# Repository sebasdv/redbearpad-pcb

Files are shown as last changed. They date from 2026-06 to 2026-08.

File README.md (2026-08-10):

# RedBearPad v2 — Mando XInput de 12 botones para RedBearLab Blend Micro

PCB de 96 × 64 mm. Mando estilo SNES orientado a juegos de plataforma que se
enumera como **control de Xbox 360 (XInput)** y Steam reconoce de forma nativa.
12 entradas a GND con pull-up interno (activo en bajo): **10 switches Redragon
SMD RGB MX Low Profile** + **2 tact CAX C39832249** (Start/Select). La Blend
Micro V1.0 va enchufada en la cara inferior (headers hembra 2×14, USB hacia el
borde superior). **Sin OLED** (eliminada respecto de la v1).

## Layout (vista desde arriba, grilla de 16 mm)

```
 L  Sel  ·  Sta  R       (fila y=16)   Sel/Sta = tact CAX
 ·  Up   ·   X   Y       (fila y=32)
 Iz Dn  Der  A   B       (fila y=48)   cruceta: Up arriba de Dn; Izq/Der en y=48
```

## Archivos

- `redbearpad.kicad_pro/.kicad_sch/.kicad_pcb` — proyecto KiCad 9 (ruteado, DRC limpio en cobre).
- `firmware/redbearpad_xinput/` — firmware XInput de 12 botones (el de producción).
- `scripts/gen_sch.py`, `scripts/gen_pcb.py` — regeneran esquemático y placement
  (ejecutar con el Python de KiCad: `...\KiCad\9.0\bin\python.exe`).
  ⚠️ Regenerar el PCB **borra el ruteo**; el ruteo actual está en el `.kicad_pcb` versionado.
- `scripts/verify_netlist.py` — valida el netlist contra el contrato de diseño (12 entradas).
- `scripts/attach_3d_models.py` — adjunta modelos 3D a los footprints ya colocados en el
  `.kicad_pcb` **sin regenerar la placa** (a diferencia de `gen_pcb.py`, no toca el ruteo).
  Solo hace falta si se rutea a mano sobre un board viejo sin modelos; una regeneración
  completa con `gen_pcb.py` ya los trae, porque viven en el `.kicad_mod` de la librería.
- `fabrication/gerbers/` — Gerbers + drill (F.Cu, B.Cu, Edge_Cuts, NPTH/PTH) regenerados.
- `docs/superpowers/specs/` — diseño aprobado de la v2.
- `docs/render_top.png`, `docs/render_bottom.png` — vistas previas 3D (`kicad-cli pcb render`).

## Ruteo

11 de las 12 nets ruteadas con **Freerouting** (autorouter, vía DSN/SES); la net
restante (SW7→A0) se ruteó a mano con una vía para cruzar la pared de pistas de
SW6/SW8. **DRC de cobre: 0 sin conectar, 0 cortos, 0 clearance.** Quedan 8 avisos
de serigrafía sobre los pads de los tact (cosméticos: el fabricante recorta la
silk sobre pads automáticamente).

## Pedido en JLCPCB

1. jlcpcb.com → "Order now" → subir un ZIP con el contenido de `fabrication/gerbers/`.
2. Opciones: 2 capas, 1.6 mm, HASL (todo por defecto sirve). Sin ensamblado.

## ⚠️ Antes de pagar

Medir con pie de metro un switch real contra el footprint: poste central Ø4.4 mm
en el centro; pines a (3.8, 3.8) y (0, 6.5) mm del centro, Ø1.2 mm. Si no
coincide, ajustar `libs/redbearpad.pretty/SW_Redragon_LowProfile_PCB_1.00u.kicad_mod`.
Verificar también el tact `SW_Tact_CAX_4.5x4.5` (cuerpo 4.5×4.5 mm, 4 patas).

## Conexiones (firmware XInput)

| Función | Pin Arduino | Botón XInput |
|---|---|---|
| Arriba / Abajo / Izquierda / Derecha | D3 / D1 / D2 / D0 | stick izq. + D-pad |
| X / Y (cara, fila superior) | D11 / D12 | X / Y |
| A / B (cara, fila inferior) | A0 / A1 | A / B |
| L / R | D8 / D9 | LB / RB |
| Select / Start | D5 / D10 | BACK / START |

Todas en `INPUT_PULLUP`, activas en bajo. La cruceta se manda como stick izquierdo
**y** D-pad para máxima compatibilidad.

Los 4 botones de cara forman un cuadrado 2×2, así que se asignan como el diamante
Xbox girado 45°, respetando las cuatro relaciones de la convención (**Y arriba, A
abajo, X izquierda, B derecha**):

```
 X  Y
 A  B
```

## Compilar y flashear (XInput)

- Placa: **"Arduino Micro w/ XInput"** (FQBN `xinput:avr:micro`, 16 MHz) del paquete
  [ArduinoXInput_Boards](https://raw.githubusercontent.com/dmadison/ArduinoXInput_Boards/master/package_dmadison_xinput_index.json)
  + librería **XInput** (David Madison). El variant 16 MHz calza con el cristal de
  la Blend Micro.
- XInput **no es CDC**: no hay Serial Monitor (LED 13 hace heartbeat). Para
  reflashear, hacer **doble-reset manual** para entrar al bootloader.

## Modelos 3D

- **Switches Redragon MX Low Profile** (los 10): modelo real
  (`libs/redbearpad.3dshapes/SW_Redragon_LowProfile_PCB_1.00u.step`), rotado 180°.
- **Blend Micro**: modelo real modelado por el usuario en Fusion 360 — PCB
  roja con los dos headers de 14 pines y un conector micro-USB detallado,
  que asoma por el borde superior de la placa tal como en la física real.
  El footprint usa el `BlendMicro_Module_V1.step` **original**, con
  `rotate (xyz 0 180 0)` en el bloque `(model ...)`: el modulo necesitaba
  dos correcciones (mirror en X para que el header quedara en el lado
  correcto, y flip en Z porque los pines apuntaban hacia afuera en vez de
  hacia J1/J2) y espejar en dos ejes distintos equivale matematicamente a
  una sola rotacion de 180° sobre Y — mas simple y sin el riesgo de una
  reflexion pura (ver mas abajo). El header del propio modulo reutiliza dos
  veces `PinHeader_1x14_P2.54mm.step` (ver abajo), mas un conector USB de
  otra fuente.
  Footprint sin pads (`BlendMicro_Module`, ref `BLENDMICRO1`): la conexión
  eléctrica real la hacen J1/J2 — sus modelos 3D de fábrica (socket hembra)
  se limpiaron (`fp.Models().clear()`, también en `gen_pcb.py` para que una
  regeneración futura no los reponga) porque quedaban duplicados sobre los
  headers que ya trae el modelo de la Blend Micro.
  `scripts/mirror_blendmicro_step.py` (CadQuery/OCC, reflexión geométrica
  real vía `Shape.mirror`) quedó sin usar pero documentado como referencia:
  es la técnica correcta para espejar un sólido B-rep en **un solo eje** (lo
  que la rotación de arriba no puede lograr). Se probó primero el camino
  obvio para el mirror en X — `scale (xyz -1 1 1)` en el bloque
  `(model ...)` — y falló: esa negación de escala invierte la orientación de
  las caras del sólido y el renderer las descarta (el cuerpo del PCB
  desaparecía casi entero, solo quedaba un borde degenerado).
  `libs/redbearpad.3dshapes/BlendMicro_Module.step` (placa plana sin
  detalle, generada con `scripts/gen_blendmicro_step.py` a partir del DXF
  oficial) queda como **fallback** por si se pierde el modelo real.
- **Regleta macho 1x14** (`libs/redbearpad.3dshapes/PinHeader_1x14_P2.54mm.step`,
  generada con `scripts/gen_pinheader_1x14.py`): no está enlazada a ningún
  footprint propio del proyecto, pero **sí se usa** — está incrustada dos
  veces dentro de `BlendMicro_Module_V1.step` (una por fila de header).
- **Tact Start/Select** (`SW_Tact_CAX_4.5x4.5`, ref `SW11`/`SW12`): modelo
  genérico `libs/redbearpad.3dshapes/TactSwitch 6x6.step` (6×6×6 mm) — no es
  el CAX C39832249 real (4.5×4.5 mm, sin STEP disponible), pero es
  reconocible como tact switch y el usuario lo acepta como placeholder.
  Cuerpo un poco más grande que el footprint (overhang leve sobre el
  courtyard); offset/escala/rotación en cero, sin ajuste necesario.

Todos los modelos ya adjuntos y visibles en `docs/render_*.png` y en el visor
3D de KiCad. Al regenerar con `gen_pcb.py` se colocan solos (viven en las
librerías); si se rutea a mano sobre un board existente, usar `scripts/attach_3d_models.py`
(switches) o `scripts/insert_blendmicro_footprint.py` (Blend Micro) para no
perder el ruteo.

## Créditos

Footprint del switch: [rgoulter/keyboard-labs](https://github.com/rgoulter/keyboard-labs).
Modelo 3D del switch: librería "Switches/REDragon_MX_LowProfile_ZT04" (autor "saper").
Core/librería XInput: [dmadison/ArduinoXInput](https://github.com/dmadison/ArduinoXInput).

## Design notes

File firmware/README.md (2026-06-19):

# Firmware de prueba — RedBearPad Keypad

Sketch `redbearpad_keypad/redbearpad_keypad.ino`: convierte la placa en un
**teclado USB HID de 8 teclas** y muestra en la OLED qué tecla está activa.
Sirve para validar PCB, switches y pantalla, y para usarlo como keypad de juego.

Mapeo de teclas:

| Botón | Tecla | Botón | Tecla |
|---|---|---|---|
| B1 | Esc | B5 | D |
| B2 | W | B6 | Espacio |
| B3 | A | B7 | Enter |
| B4 | S | B8 | Shift (izq.) |

Cada tecla se mantiene pulsada mientras el switch esté presionado (press/release).

## Requisitos

1. **Core del Blend Micro** `redbearlab:avr` (repo `blend-micro-boards`).
   Comprobar: `arduino-cli core list` debe listar `redbearlab:avr`.
2. **Librerías** (todas desde el Gestor de librerías de Arduino):
   - **HID-Project** — NicoHood. Provee el `Keyboard` USB HID. Se usa esta (y no
     la librería "Keyboard" del core ni "Joystick") porque su header
     `HID-Project.h` no colisiona con otras librerías y trae teclado, gamepad y
     más en un solo paquete.
   - **Adafruit SSD1306** y **Adafruit GFX Library**.

## Compilar

Verificado en esta máquina con arduino-cli (20026 B flash / 69 %, 668 B RAM),
usando solo librerías del Gestor (sin rutas extra):

```powershell
$cli = "C:\redbearpad\tools\arduino-cli\arduino-cli.exe"
& $cli lib install "HID-Project" "Adafruit SSD1306" "Adafruit GFX Library"
& $cli compile --fqbn redbearlab:avr:blendmicro16 firmware\redbearpad_keypad
```

FQBN: `redbearlab:avr:blendmicro16` (16 MHz, overclock) o
`redbearlab:avr:blendmicro8` (8 MHz). Ambas compilan igual.

## Cargar a la placa

El Blend Micro usa el bootloader Caterina (protocolo avr109, *1200 bps touch*).
Conectar por USB, identificar el puerto COM y subir:

```powershell
& $cli upload --fqbn redbearlab:avr:blendmicro16 -p COM<N> firmware\redbearpad_keypad
```

Desde el IDE de Arduino: seleccionar la placa *Blend Micro 3.3V/16MHz*, el puerto,
y pulsar *Subir*. Si la subida no arranca, pulsar *reset* en la placa justo cuando
el IDE indique "Subiendo" (el bootloader Caterina solo expone el puerto ~8 s).

> La carga la haces tú con la placa conectada; aquí solo se validó la compilación.

## Comprobar que funciona

- **PC:** abrir cualquier editor de texto y pulsar los switches: deben escribirse
  las teclas (W/A/S/D, Espacio, Enter) y actuar Esc y Shift.
- **Monitor serie** (115200 baudios): imprime `RedBearPad listo - keypad 8 teclas`
  y un eco `<tecla> pulsado` / `<tecla> soltado` en cada cambio.
- **OLED:** muestra `RedBearPad keypad` y una rejilla Esc/W/A/S/D/Spc/Ent/Sft;
  la tecla pulsada se resalta en vídeo inverso. Si la pantalla no responde,
  revisar que su dirección I2C sea `0x3C` (algunos módulos usan `0x3D`: cambiar
  `OLED_ADDR`).

## Mapeo de pines (fijado por la PCB)

| Botón | Pin | Botón | Pin |
|---|---|---|---|
| B1 | D5 | B5 | D11 |
| B2 | D8 | B6 | D12 |
| B3 | D9 | B7 | A0 |
| B4 | D10 | B8 | A1 |

OLED I2C: SDA→D2, SCL→D3, VCC→3.3 V, GND→GND.

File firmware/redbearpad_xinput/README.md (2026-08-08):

# Firmware XInput (mando Xbox 360) — RedBearPad

Sketch `redbearpad_xinput/redbearpad_xinput.ino`: hace que la placa **enumere como un mando
Xbox 360 (XInput)**, que Steam y los juegos reconocen **nativamente**.

## Por qué XInput

El firmware gamepad HID genérico funciona en `joy.cpl` pero **muchos juegos solo aceptan
mandos XInput (Xbox)** y vía Steam Input no había caso. XInput resuelve esto de raíz: la placa
ES un mando Xbox para Windows. ✅ Verificado: Steam lo reconoce.

## Build — NO es el setup normal, leer esto

Este sketch **no** se compila con el paquete `redbearlab:avr`. Usa el core XInput.

### 1. Instalar el soporte XInput (una vez)

- Arduino IDE → **Archivo → Preferencias → URLs adicionales de gestor de placas**, añadir:
  ```
  https://raw.githubusercontent.com/dmadison/ArduinoXInput_Boards/master/package_dmadison_xinput_index.json
  ```
- **Herramientas → Placa → Gestor de placas** → instalar **"XInput AVR Boards"** (dmadison).
- **Herramientas → Gestor de librerías** → instalar **"XInput"** (David Madison).

### 2. Placa correcta: "Arduino Micro w/ XInput"

**Selecciona `Arduino Micro w/ XInput`** (FQBN `xinput:avr:micro`), NO el Pro Micro 8 MHz.

Motivo: la Blend Micro tiene cristal de **16 MHz**. `USBCore.cpp` fija el bit `PINDIV` del PLL
**en tiempo de compilación** según `F_CPU`: con `F_CPU=16000000` lo activa (divide el cristal
de 16 MHz por 2 → 8 MHz de entrada al PLL → 48 MHz de USB, correcto). Cualquier variant de
8 MHz —el Pro Micro, o el core `blendmicro8`— lo *limpia*, asumiendo un cristal de 8 MHz; con
el cristal real de 16 MHz el PLL sale a 96 MHz y **el USB no enumera** (ni siquiera aparece
como dispositivo desconocido).

⚠️ **Por eso este sketch no se compila con `blendmicro8`**, aunque sea el core correcto para el
keypad y el diagnóstico. Si lo haces, la placa queda muda en USB.

### Overclock: resuelto con prescaler en runtime

El variant Micro corre el CPU a 16 MHz @ 3.3 V, que está **fuera de spec** (el 32U4 a 3.3 V
sólo llega a ~10.7 MHz) y glitcheaba al calentar, acoplando botones vecinos tras ~5 min.

Solución: `setup()` baja el CPU a 8 MHz con el prescaler (`CLKPR`), **sin tocar el PLL**. Como
`PINDIV` ya quedó bien fijado al compilar, el USB sigue a 48 MHz y el mando enumera como Xbox
360, pero el CPU vuelve a estar en spec. Verificado: 30 min de Steam sin cuelgues ni fantasmas.

Contrapartida: `millis()` y todo el timing corren a la mitad → muestreo ~2 ms, debounce ~24 ms
y **heartbeat del LED 13 a ~0.5 Hz** (si lo ves a 1 Hz, el prescaler no se aplicó).

### 3. Subir

```powershell
$cli = "C:\redbearpad\tools\arduino-cli\arduino-cli.exe"
& $cli compile --fqbn xinput:avr:micro firmware\redbearpad_xinput
& $cli upload  --fqbn xinput:avr:micro -p COM<N> firmware\redbearpad_xinput
```

O desde el IDE: placa "Arduino Micro w/ XInput", puerto COM, Subir.

## ⚠️ Re-flasheo: doble-reset manual

Una vez corriendo XInput, la placa **ya no es un dispositivo serie (CDC)**, así que el
auto-reset por toque a 1200 bps **no funciona**. Para volver a subir cualquier firmware
(otra versión de XInput, o volver al gamepad/keypad):

1. Inicia la subida en el IDE.
2. Pulsa **reset dos veces rápido** en la placa → entra al bootloader Caterina (~8 s).
3. La subida arranca en esa ventana.

## Sin Serial Monitor

XInput no expone CDC → **no hay monitor serie**. Diagnóstico = el **LED 13 parpadea ~0.5 Hz**
("firmware vivo", a la mitad por el prescaler) y la observación en Windows (`joy.cpl`,
hardwaretester.com/gamepad, Steam). Para diagnóstico con serie, usar
`firmware/diagnostico_pines/` con el core `blendmicro8`.

## Mapeo (PCB v2, 12 botones)

| Switch | Posición en la placa | Pin | Función Xbox |
|---|---|---|---|
| SW1 / SW2 / SW3 / SW4 | cruceta (arriba/abajo/izq/der) | D3 / D1 / D2 / D0 | Stick izq. + D-pad |
| SW5 | cara, arriba-izq | D11 | X |
| SW6 | cara, arriba-der | D12 | Y |
| SW7 | cara, abajo-izq | A0 | A |
| SW8 | cara, abajo-der | A1 | B |
| SW9 / SW10 | hombros | D8 / D9 | LB / RB |
| SW11 / SW12 | tact centrales | D5 / D10 | BACK / START |

Los 4 botones de cara forman un cuadrado 2×2, así que se asignan como el diamante Xbox girado
45° (`X Y` arriba, `A B` abajo), respetando **Y arriba, A abajo, X izquierda, B derecha**.

## Probar

- **Windows:** `joy.cpl` → "Controller (XBOX 360 For Windows)" → botones, dpad y stick.
- **Steam:** Configuración → Controlador → aparece como mando Xbox; o directo en un juego.

## No incluye (a futuro)

- OLED (la v2 no la lleva; se podría reincorporar el visualizador de mando vía I2C,
  event-driven, que convive con XInput).
- Gatillos analógicos y segundo stick (la PCB v2 sólo tiene entradas digitales).
- Variant XInput a medida de 8 MHz: quedó **innecesario**, el prescaler en runtime resuelve
  el overclock sin salir del variant Micro de fábrica.

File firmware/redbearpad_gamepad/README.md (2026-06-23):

# Firmware Gamepad — RedBearPad

Sketch `redbearpad_gamepad/redbearpad_gamepad.ino`: convierte la placa en un
**gamepad USB HID** con cruceta + 4 botones, para usar en Steam.

## Mapeo

| Switch | Rol gamepad |
|---|---|
| SW2 / SW3 / SW4 / SW5 | Cruceta Arriba / Izq / Abajo / Der (con diagonales) |
| SW1 | Botón 1 |
| SW6 | Botón 2 |
| SW7 | Botón 3 |
| SW8 | Botón 4 |

## Requisitos

- Core `redbearlab:avr` (repo `blend-micro-boards`).
- Librerías (Gestor de librerías): **HID-Project** (NicoHood), **Adafruit SSD1306**,
  **Adafruit GFX Library**.

## Compilar y subir

```powershell
$cli = "C:\redbearpad\tools\arduino-cli\arduino-cli.exe"
& $cli compile --fqbn redbearlab:avr:blendmicro8 firmware\redbearpad_gamepad
& $cli upload  --fqbn redbearlab:avr:blendmicro8 -p COM<N> firmware\redbearpad_gamepad
```

Usar **blendmicro8** (8 MHz). El 16 MHz es overclock fuera de spec a 3.3 V y causa
fallos erráticos.

## Probar

- **Windows:** `joy.cpl` → "RedBearPad" → mover cruceta y pulsar los 4 botones.
- **Monitor serie** (115200): al arrancar imprime `dpad self-test: PASS`, el
  autodiagnóstico de pines y el escaneo I2C; luego un eco `dpad=N botones=XXXX`.
- **Steam:** Configuración → Controlador → habilitar soporte de controles genéricos;
  configurar en Steam Input (la cruceta se puede asignar a d-pad o stick).

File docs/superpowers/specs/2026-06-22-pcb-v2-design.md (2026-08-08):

# RedBearPad v2 — Rediseño del PCB (mando XInput de 12 botones) — Diseño

**Fecha:** 2026-06-22
**Estado:** Aprobado
**Rama:** `pcb-rediseno`

## Problema

El RedBearPad v1 tiene 8 switches + OLED. Se quiere un mando orientado a juegos de
plataforma con **12 entradas** (estilo SNES) y **sin OLED**, manteniendo el mismo tamaño de
board (96×64 mm) y la Blend Micro como cerebro. El firmware destino es **XInput** (mando
Xbox 360), que ya funciona en la v1.

El layout y el mapeo de funciones fueron definidos por el usuario sobre un DXF modificado
(`redbearpad_actual_MOD.dxf`, analizado y conservado en el repo como referencia).

## Alcance

- **Incluye:** regenerar el PCB (esquemático + ruteo) a 12 entradas con el layout/mapeo
  aprobado; agregar el footprint del tact CAX; actualizar `verify_netlist.py`; extender el
  firmware XInput a 12 botones.
- **No incluye:** OLED, BLE, cambios de tamaño de board, segundo stick o gatillos analógicos.

## Hardware

### Board
- Contorno **96 × 64 mm**, esquinas r=1 (igual que v1).
- **4 agujeros de montaje** Ø3.1 en las esquinas (conservados).
- **Blend Micro** enchufada por debajo: headers hembra **2×14** en x≈40.4 y x≈55.6
  (conservados, mismo cableado de alimentación/USB que v1).
- **OLED eliminada** (se quita el conector J3 y sus nets SDA/SCL/VCC).

### Entradas (12) — posiciones (x, y desde arriba, mm) y mapeo

| Función | Posición | Componente |
|---|---|---|
| L | (16, 16) | switch Redragon low-profile 1u |
| R | (80, 16) | switch Redragon |
| Select | (32, 16) | **tact CAX C39832249** (4.5×4.5, DIP 4P) |
| Start | (64, 16) | **tact CAX C39832249** |
| Arriba | (32, 32) | switch Redragon |
| A | (64, 32) | switch Redragon |
| B | (80, 32) | switch Redragon |
| Izquierda | (16, 48) | switch Redragon |
| Abajo | (32, 48) | switch Redragon |
| Derecha | (48, 48) | switch Redragon |
| X | (64, 48) | switch Redragon |
| Y | (80, 48) | switch Redragon |

**Total: 10 switches Redragon + 2 tact CAX.** Espaciado en grilla de **16 mm** (igual que v1;
keycaps 14.2 mm → 1.8 mm de aire, courtyards 1u se solapan levemente, aceptado por el usuario).

Cada entrada es un pin a GND con pull-up interno (activo en LOW), igual que v1.

### Asignación de pines (GPIO)

12 GPIO del set limpio del ATmega32U4, **evitando** D6/D7 (nRF8001), D13 (LED) y los de SPI
(MISO/MOSI/SCK/SS). Candidatos: D0, D1, D2, D3, D5, D8, D9, D10, D11, D12, A0–A5.

La asignación exacta switch→pin la **fija la generación del PCB** buscando ruteo limpio y
**evitando adyacencias problemáticas** (en v1 un puente D9↔D10 cruzaba izquierda/abajo). El
netlist resultante es el contrato; el firmware se ajusta a esa asignación.

## Firmware (XInput, extender el existente)

Base: `firmware/redbearpad_xinput/redbearpad_xinput.ino`. Cambios:
- 12 entradas con el debounce por integrador (igual patrón).
- Cruceta (Arriba/Abajo/Izq/Der) → **stick izquierdo** (`setJoystick`, diagonales por SOCD)
  **y** D-pad (`setDpad`).
- A/B/X/Y → `setButton(BUTTON_A/B/X/Y, ...)`.
- L/R → `setButton(BUTTON_LB/RB, ...)`.
- Select → `BUTTON_BACK`; Start → `BUTTON_START`.
- LED 13 heartbeat (sin serial). Compila para `xinput:avr:micro`.

## Componentes / librería

- **Footprint nuevo:** tact CAX `C39832249` (4.5×4.5 mm, DIP, 4 patas) en
  `libs/redbearpad.pretty/`. Dimensiones del datasheet LCSC (cuerpo 4.5×4.5, paso de patas a
  confirmar del datasheet).
- Footprint del switch Redragon: el existente (`SW_Redragon_LowProfile_PCB_1.00u`).

## Generación y verificación

- Actualizar `scripts/gen_sch.py` y `scripts/gen_pcb.py` para producir el esquemático y el PCB
  v2 (12 entradas, footprints y posiciones nuevas, OLED fuera, mapeo de pines).
- Actualizar `scripts/verify_netlist.py` con el contrato de 12 entradas (cada switch a su pin +
  GND; sin nets de OLED).
- Verificación: ERC 0, DRC 0, `verify_netlist.py` OK; gerbers JLCPCB regenerados.
- Firmware: compila para `xinput:avr:micro`; el usuario prueba en Steam (mando Xbox de 12).

## Notas de diseño

- Cruceta: Arriba (32,32) encima de Abajo (32,48); Izq/Der en la fila y48. Decisión ergonómica
  del usuario (confirmada), no un error.
- El DXF `redbearpad_actual_MOD.dxf` queda como referencia del layout físico aprobado.

## Fuera de alcance / futuro

- Carcasa 3D, segundo stick, gatillos analógicos, RGB.

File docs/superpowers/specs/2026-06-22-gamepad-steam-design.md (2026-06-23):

# RedBearPad como gamepad HID para Steam — Diseño

**Fecha:** 2026-06-22
**Estado:** Aprobado

## Problema

El RedBearPad (8 switches sobre una RedBearLab Blend Micro, ATmega32U4) funciona hoy
como **teclado USB HID** (`firmware/redbearpad_keypad/redbearpad_keypad.ino`, con
HID-Project + Keyboard). Se quiere una variante que el PC y **Steam** reconozcan como
**gamepad**, para jugar con cruceta + botones en vez de teclas.

## Solución

Sketch **nuevo e independiente** que reusa la misma placa y librería pero enumera como
**gamepad HID genérico** mediante la clase `Gamepad` de HID-Project (ya instalada). No
requiere XInput ni cambios de bootloader. Steam lo reconoce como control genérico y se
configura con **Steam Input**.

El keypad actual se conserva sin tocar; el usuario elige qué sketch flashear.

## Alcance

- **Incluye:** firmware gamepad (cruceta + 4 botones), OLED con estado del mando,
  diagnósticos heredados, verificación de compilación y detección en Windows/Steam.
- **No incluye:** XInput/emulación Xbox, sticks analógicos reales (no hay potenciómetros
  en el hardware), cambios en la PCB, resolver el montaje físico de la OLED (su conexión ya
  quedó funcional; aquí solo se mejora el refresco).

## Estructura de archivos

```
firmware/redbearpad_gamepad/redbearpad_gamepad.ino   (NUEVO; la carpeta ya existe vacía)
docs/superpowers/specs/2026-06-22-gamepad-steam-design.md  (este documento)
```

No se modifica `redbearpad_keypad/`.

## Componentes

### 1. Enumeración HID

- `#include <HID-Project.h>`, objeto global `Gamepad`.
- `Gamepad.begin()` en `setup()`. El dispositivo aparece como gamepad HID; en Windows se
  ve en `joy.cpl`, y en Steam como control genérico ("RedBearPad").

### 2. Lectura de switches (reutilizado del keypad)

Pines (fijados por la PCB), todos `INPUT_PULLUP`, activo en LOW:

| Switch | Pin | Rol gamepad |
|---|---|---|
| SW2 | D8  | Cruceta ARRIBA |
| SW3 | D9  | Cruceta IZQUIERDA |
| SW4 | D10 | Cruceta ABAJO |
| SW5 | D11 | Cruceta DERECHA |
| SW1 | D5  | Botón 1 |
| SW6 | D12 | Botón 2 |
| SW7 | A0  | Botón 3 |
| SW8 | A1  | Botón 4 |

Se reutiliza el **debounce por integrador con histéresis** y el **muestreo a intervalo
fijo (1 ms)** del keypad (es la lógica que hace el filtro independiente de la velocidad
del loop). Cada switch tiene su integrador; el estado filtrado (`estadoPrev[i]`)
alimenta tanto la cruceta como los botones.

### 3. Cruceta (hat) con diagonales

Los 4 estados filtrados de dirección se combinan **cada ciclo** en un único valor de hat
(8 direcciones + centro) y se envía con `Gamepad.dPad1(dir)`:

- Solo ARRIBA → `GAMEPAD_DPAD_UP`; ARRIBA+IZQUIERDA → `GAMEPAD_DPAD_UP_LEFT`; etc.
- Combinaciones opuestas simultáneas (ARRIBA+ABAJO) → se cancelan a centro.
- Sin dirección → `GAMEPAD_DPAD_CENTERED`.

La cruceta se recalcula a partir de los estados, no por eventos sueltos, para que las
diagonales sean correctas.

### 4. Botones de acción

Los 4 switches de acción mapean a `Gamepad.press(n)` / `Gamepad.release(n)` con
`n = 1..4`, disparados al cambiar el estado filtrado correspondiente.

### 5. Envío del reporte

Tras actualizar hat y botones en un ciclo, si hubo algún cambio se llama a
`Gamepad.write()` una vez (no en cada vuelta) para enviar el reporte HID.

### 6. OLED (opcional, con refresco corregido)

- Detección honesta por I2C (probe de ACK antes de `begin`, como en el keypad mejorado),
  prueba 0x3C/0x3D, con `Wire.setWireTimeout` para no congelar el loop.
- Dibuja el estado del mando: indicador de dirección de la cruceta (flechas/cruz) y los
  4 botones, resaltando los activos.
- **Refresco solo cuando cambia el estado** (se elimina el redibujo periódico de 250 ms
  que causaba el parpadeo/"movimiento" observado). Si no hay OLED, el mando funciona
  igual (`oledOk` protege todo).

### 7. Diagnósticos (heredados)

- Autodiagnóstico de pines en `setup()` (todos deben leer HIGH en reposo).
- `escanearI2C()` + estado real de la OLED por el monitor serie (115200).
- Eco por serie de dirección de cruceta y botones al cambiar, para depurar sin Steam.

## Lado Steam / Windows

- **Windows:** `joy.cpl` → "RedBearPad" → la pestaña de propiedades muestra los 4 botones
  y la cruceta; sirve para validar antes de Steam.
- **Steam:** *Configuración → Controlador* habilitar el soporte de controles genéricos;
  el mando aparece en Steam Input y se le asigna layout (cruceta → d-pad o stick, botones
  1-4 → A/B/X/Y o lo que el juego necesite).

## Manejo de errores

- OLED ausente o muda → `oledOk=false`, el mando sigue operativo.
- Bus I2C trabado → el timeout de `Wire` aborta y no congela el envío HID.
- Direcciones opuestas simultáneas en la cruceta → se resuelven a centro (sin estado
  inválido de hat).

## Verificación

1. Compilar para `redbearlab:avr:blendmicro8` (y `blendmicro16` como sanity) con
   arduino-cli; debe enlazar sin errores.
2. Subir a la placa (lo hace el usuario) y abrir el monitor serie: ver el eco de
   dirección/botones y el bloque de diagnóstico.
3. **Windows `joy.cpl`:** confirmar que los 8 switches mueven cruceta/botones correctos,
   incluidas diagonales.
4. **Steam:** confirmar que aparece como control y es configurable en Steam Input.

Recordatorio: usar siempre **8 MHz** (`blendmicro8`); 16 MHz es overclock fuera de spec
a 3.3 V (causa fallos erráticos; documentado en el paquete `blend-micro-boards`).

## Fuera de alcance / futuro

- Sticks analógicos (requeriría hardware nuevo).
- Modo combinado teclado+gamepad simultáneo.
- Perfil/configuración guardada en EEPROM.

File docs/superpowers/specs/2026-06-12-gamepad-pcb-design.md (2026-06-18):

# RedBearPad — Gamepad PCB de 8 botones con OLED — Diseño

**Fecha:** 2026-06-12
**Estado:** Aprobado
**Herramienta:** KiCad 9.0.x (instalado), verificación con `kicad-cli`

## Objetivo

PCB de un gamepad USB HID de 8 botones con pantalla OLED, controlado por una placa
RedBearLab Blend Micro V1.0 (ATmega32U4 + nRF8001, 3.3 V) montada como módulo
enchufable. Entrega lista para fabricar en JLCPCB (PCB desnuda, sin ensamblado SMD:
el diseño no lleva componentes SMD). El firmware HID queda fuera de alcance.

## Restricciones de partida (del usuario)

- Placa de **96 × 64 mm**, geometría según `C:\redbearpad\REFERENCE_PCB.dxf`.
- Switches **Redragon SMD RGB MX Low Profile** (3 pines, ya comprados). Sin LEDs
  en la PCB (decisión: se eliminaron los LEDs del diseño).
- Pantalla **OLED 128×32 px, 0.91"/0.94", I2C de 4 pines** (ya comprada).
- Blend Micro montado **en la cara inferior**, enchufable (headers hembra).

## Convención de coordenadas

El DXF de referencia usa origen en la esquina superior izquierda con Y negativa
hacia abajo. En KiCad se usa la misma geometría con **Y positiva hacia abajo**:
`(x_kicad, y_kicad) = (x_dxf, −y_dxf)`. Todas las coordenadas de este documento
están en formato KiCad (mm), origen en la esquina superior izquierda de la placa.

## Geometría (fiel al DXF de referencia)

- **Contorno:** rectángulo 96 × 64 mm, esquinas redondeadas r = 1 mm (capa Edge.Cuts).
- **4 perforaciones de montaje M3:** Ø3.1 mm NPTH en (4,4), (92,4), (4,60), (92,60).
- **8 switches** (centro del poste):

| Ref | Posición (x, y) | Clúster |
|---|---|---|
| SW1 | (16, 16) | izquierdo |
| SW2 | (32, 32) | izquierdo |
| SW3 | (16, 48) | izquierdo |
| SW4 | (32, 48) | izquierdo |
| SW5 | (48, 48) | central-inferior |
| SW6 | (64, 32) | derecho |
| SW7 | (80, 32) | derecho |
| SW8 | (80, 48) | derecho |

- **Zona OLED (cara superior):** x 29–66, y 8–19 (37 × 11 mm). Header hembra de
  4 pines paso 2.54 mm; el módulo OLED queda en voladizo sobre la zona.
- **Zona Blend Micro (cara inferior):** x 38.5–57.5, y 0–42, centrada en x = 48.
  El conector micro-USB del módulo queda en el borde superior de la placa (y = 0)
  para el acceso del cable.

## Arquitectura eléctrica

Sin matriz y sin diodos: cada switch conecta un GPIO a GND; el firmware usa
`INPUT_PULLUP`. No hay componentes SMD ni pasivos en la PCB — solo conectores,
switches y perforaciones.

### Asignación de pines

| Señal | Pin Blend Micro | Nota |
|---|---|---|
| SW1 | D5 | |
| SW2 | D8 | |
| SW3 | D9 | |
| SW4 | D10 | |
| SW5 | D11 | |
| SW6 | D12 | |
| SW7 | A0 | digital con pull-up |
| SW8 | A1 | digital con pull-up |
| OLED SDA | D2 (SDA) | I2C hardware |
| OLED SCL | D3 (SCL) | I2C hardware |
| OLED VCC | V33 (3.3 V) | regulador del módulo |
| OLED GND | GND | |

Se evitan deliberadamente: D0/D1 (serial libre para debug), D13 (LED onboard
interfiere con pull-up), D4/D6/D7 y SPI (reservados por el BLE nRF8001 interno).

## Footprints

### Switch Redragon Low Profile (3 pines)

Fuente: `rgoulter/keyboard-labs` (`pcb/ProjectLocal.pretty/`), usado en un teclado
real fabricado con estos switches (fork `Apiratchai/cheapis-redragon-lowprofile`).
Copia local ya guardada en `libs/footprints/SW_Redragon_LowProfile_PCB_1.00u.kicad_mod`.

- Poste central: NPTH Ø4.4 mm en (0, 0) del footprint.
- Pin 1: (3.8, 3.8), taladro Ø1.2 mm, pad Ø2.2 mm.
- Pin 2: (0, 6.5), taladro Ø1.2 mm, pad Ø2.2 mm.

### Zócalo Blend Micro (footprint propio, a crear)

Datos extraídos del DXF oficial (`upstream/Blend/PCB/Blend_Micro.dxf`):

- Módulo: 18.4 × 42.09 mm. Pines: 2 filas × 14, paso 2.54 mm, separación entre
  filas 15.24 mm (0.6"), taladros para header hembra estándar (Ø1.0 mm, pad Ø1.7 mm).
- En coordenadas de placa: filas en x = 40.38 y x = 55.62; pines en
  y = 1.667 + n·2.54 (n = 0…13), es decir y 1.667 … 34.687. El extremo USB del
  módulo coincide con el borde superior (y = 0); solo el conector micro-USB
  sobresale (~1 mm).
- **El footprint se coloca en la cara inferior (B.Cu)**: al estar el módulo boca
  abajo, las columnas izquierda/derecha se ven espejadas desde la cara superior.
  El mapeo de señales del footprint debe construirse explícitamente espejado y
  verificarse contra `BlendMicro_Pins.png` (columna izquierda del módulo desde el
  USB hacia arriba: GND, GND, VIN, SS, CLK, MOSI, MISO, /RST, D0, D1, D2, D3, D5,
  D8 — columna derecha desde el USB: GND, V33, AREF, A5, A4, A3, A2, A1, A0, D13,
  D12, D11, D10, D9).
- Serigrafía en ambas caras indicando orientación del módulo y posición del USB.

### Header OLED

Header hembra 1×4, paso 2.54 mm, en la cara superior. El módulo comprado tiene
los pines en el **borde corto izquierdo** (columna vertical). El orden de header
en la placa, verificado contra el ajuste físico del módulo, es de arriba hacia
abajo **SDA, SCL, VCC, GND** (la conexión eléctrica se preserva — SDA→SDA, etc.;
este orden coloca cada pin del módulo en su pad correcto al enchufarlo).

El header se coloca como columna vertical 1×4 en el extremo izquierdo de la zona
SCREEN (x ≈ 30, pines centrados verticalmente en la zona: y = 9.7, 12.24, 14.78,
17.32, paso 2.54 mm), con **pin 1 = SDA arriba** y pin 4 = GND abajo. El cuerpo
del módulo queda en voladizo hacia la derecha cubriendo el resto de la zona.

## Reglas de diseño y fabricación

- 2 capas, FR-4 1.6 mm, acabado HASL — perfil estándar JLCPCB.
- Planos de tierra en ambas caras.
- Pistas: 0.25 mm señal, 0.5 mm alimentación (VIN/V33). Clearance 0.2 mm.
- Sin BOM/CPL: pedido de PCB desnuda, solo Gerbers + drill en ZIP formato JLCPCB.

## Estructura del proyecto

```
gamepad-pcb/
├── redbearpad.kicad_pro / .kicad_sch / .kicad_pcb
├── libs/footprints/            # Librería local del proyecto (Redragon SW, zócalo Blend Micro, etc.)
├── fabrication/                # Gerbers + drill (ZIP para JLCPCB), generado por kicad-cli
├── docs/superpowers/specs/     # este documento
└── README.md                   # cómo abrir, validar y pedir a JLCPCB
```

## Verificación

Automatizada en esta máquina con `kicad-cli`:

1. **ERC** sobre el esquemático: sin errores.
2. **DRC** sobre la PCB con reglas compatibles JLCPCB: sin errores.
3. Export de **Gerbers + drill** y empaquetado ZIP.
4. **Renders PNG** de ambas caras (`kicad-cli pcb render`) para revisión visual
   del usuario.

Checkpoints físicos del usuario **antes de enviar a fabricar**:

1. ~~Medir los 3 agujeros del switch Redragon~~ — **resuelto**: el usuario confirmó
   que el footprint coincide con el switch físico.
2. ~~Confirmar el orden de pines del módulo OLED~~ — **resuelto**: orden corregido
   a SDA, SCL, VCC, GND según el ajuste físico del módulo.
3. Revisar los renders (posiciones, serigrafía, orientación del Blend Micro).

## Riesgos

- **Footprint del switch:** es de la comunidad, no de un datasheet oficial.
  Mitigación: proviene de un diseño fabricado y funcional + checkpoint de medición.
- **Espejado del zócalo Blend Micro:** error clásico al montar módulos en la cara
  inferior. Mitigación: mapeo espejado explícito en el footprint, serigrafía de
  orientación y revisión del render inferior.
- ~~**Orden de pines OLED**~~ — riesgo eliminado: orden y posición verificados
  con fotografía del módulo físico.

## Fuera de alcance

- Firmware del gamepad (sketch HID) — proyecto posterior.
- Carcasa/case y keycaps.
- LEDs bajo los switches (eliminados por decisión del usuario).
- Uso del BLE (el diseño no lo bloquea: los pines BLE quedan libres en el módulo).

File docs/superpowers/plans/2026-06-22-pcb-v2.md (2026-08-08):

# RedBearPad v2 (PCB XInput 12 botones) — Plan de Implementación

> **For agentic workers:** REQUIRED SUB-SKILL: Use superpowers:subagent-driven-development (recommended) or superpowers:executing-plans to implement this plan task-by-task. Steps use checkbox (`- [ ]`) syntax for tracking.

**Goal:** Regenerar el PCB del RedBearPad a 12 entradas (10 switches Redragon + 2 tact CAX, sin OLED) con el layout/mapeo aprobado, y extender el firmware XInput a 12 botones.

**Architecture:** El PCB se genera por scripts: `gen_sch.py` (esquemático/nets vía global labels), exportación de netlist desde KiCad, `gen_pcb.py` (placement + **ruteo hand-coded** + zonas + serigrafía con pcbnew), `verify_netlist.py` (contrato). Se actualizan los cuatro + un footprint nuevo, y el sketch XInput.

**Tech Stack:** KiCad 9 (pcbnew Python + kicad-cli), Python, Arduino (XInput).

**Spec:** `docs/superpowers/specs/2026-06-22-pcb-v2-design.md`

**Entorno:**
- Python de KiCad (con `pcbnew`): `C:\Users\sebastian.duarte\AppData\Local\Programs\KiCad\9.0\bin\python.exe`
- kicad-cli: `C:\Users\sebastian.duarte\AppData\Local\Programs\KiCad\9.0\bin\kicad-cli.exe`
- arduino-cli: `C:\redbearpad\tools\arduino-cli\arduino-cli.exe`
- Repo `C:\redbearpad\gamepad-pcb`, rama `pcb-rediseno`.

**Aviso de altitud:** el ruteo (Task 6) es iterativo por naturaleza — las polilíneas de pista se desarrollan corriendo `gen_pcb.py` + DRC y ajustando, no se pueden pre-escribir. Las demás tareas llevan código completo.

## Contrato de mapeo (función ↔ posición ↔ pin Blend Micro ↔ GPIO ↔ ref)

| Ref | Función | Pos (x,y) | Footprint | Header.pin | GPIO |
|---|---|---|---|---|---|
| SW1 | Arriba | (32,32) | Redragon | J1.12 | D3 |
| SW2 | Abajo | (32,48) | Redragon | J1.10 | D1 |
| SW3 | Izquierda | (16,48) | Redragon | J1.11 | D2 |
| SW4 | Derecha | (48,48) | Redragon | J1.9 | D0 |
| SW5 | A | (64,32) | Redragon | J2.12 | D11 |
| SW6 | B | (80,32) | Redragon | J2.11 | D12 |
| SW7 | X | (64,48) | Redragon | J2.9 | A0 |
| SW8 | Y | (80,48) | Redragon | J2.8 | A1 |
| SW9 | L | (16,16) | Redragon | J1.14 | D8 |
| SW10 | R | (80,16) | Redragon | J2.14 | D9 |
| SW11 | Select | (32,16) | **tact CAX** | J1.13 | D5 |
| SW12 | Start | (64,16) | **tact CAX** | J2.13 | D10 |

GND: pad 2 de cada switch + J1.1, J1.2, J2.1. **Sin** nets SDA/SCL/+3V3 ni J3 (OLED fuera).
Pines evitados: D6/D7 (nRF8001, no en header), D13 (J2.10, LED), SPI (J1.4–8), AREF (J2.3), VIN (J1.3).

---

### Task 1: Footprint del tact CAX C39832249

**Files:**
- Create: `libs/redbearpad.pretty/SW_Tact_CAX_4.5x4.5.kicad_mod`

- [ ] **Step 1: Crear el footprint** (4 pads THT en cuadrado de 4.5 mm; las 2 patas de cada lado van al mismo net — pads 1 y 2 = terminal A, pads 3 y 4 = terminal B). Patrón típico de tact 4.5×4.5 de 4 patas: pads en (±2.25, ±2.5). Verificar contra el datasheet LCSC del C39832249 antes de fabricar.

```
(footprint "SW_Tact_CAX_4.5x4.5" (version 20240108) (generator "manual")
  (layer "F.Cu")
  (attr through_hole)
  (fp_text reference "REF**" (at 0 -3.6) (layer "F.SilkS") (effects (font (size 1 1) (thickness 0.15))))
  (fp_text value "SW_Tact_CAX" (at 0 3.6) (layer "F.Fab") (effects (font (size 1 1) (thickness 0.15))))
  (fp_line (start -2.25 -2.25) (end 2.25 -2.25) (stroke (width 0.12) (type default)) (layer "F.SilkS"))
  (fp_line (start -2.25 2.25) (end 2.25 2.25) (stroke (width 0.12) (type default)) (layer "F.SilkS"))
  (fp_line (start -2.25 -2.25) (end -2.25 2.25) (stroke (width 0.12) (type default)) (layer "F.SilkS"))
  (fp_line (start 2.25 -2.25) (end 2.25 2.25) (stroke (width 0.12) (type default)) (layer "F.SilkS"))
  (fp_rect (start -2.85 -2.85) (end 2.85 2.85) (stroke (width 0.05) (type default)) (fill none) (layer "F.CrtYd"))
  (pad "1" thru_hole circle (at -2.25 -2.5) (size 1.5 1.5) (drill 0.9) (layers "*.Cu" "*.Mask"))
  (pad "1" thru_hole circle (at 2.25 -2.5) (size 1.5 1.5) (drill 0.9) (layers "*.Cu" "*.Mask"))
  (pad "2" thru_hole circle (at -2.25 2.5) (size 1.5 1.5) (drill 0.9) (layers "*.Cu" "*.Mask"))
  (pad "2" thru_hole circle (at 2.25 2.5) (size 1.5 1.5) (drill 0.9) (layers "*.Cu" "*.Mask"))
)
```

Nota: dos pads con número "1" y dos con "2" hacen que KiCad los una eléctricamente (terminal A=net del switch, B=GND), igual que un SW_Push de 2 pines.

- [ ] **Step 2: Verificar que KiCad lo carga**

```powershell
$py = "C:\Users\sebastian.duarte\AppData\Local\Programs\KiCad\9.0\bin\python.exe"
& $py -c "import pcbnew; fp=pcbnew.FootprintLoad(r'C:\redbearpad\gamepad-pcb\libs\redbearpad.pretty','SW_Tact_CAX_4.5x4.5'); print('OK' if fp else 'FALLO'); print('pads:', fp.GetPadCount())"
```
Esperado: `OK` y `pads: 4`. Si falla, revisar la sintaxis del .kicad_mod.

- [ ] **Step 3: Commit**

```powershell
git -C C:\redbearpad\gamepad-pcb add libs/redbearpad.pretty/SW_Tact_CAX_4.5x4.5.kicad_mod
git -C C:\redbearpad\gamepad-pcb commit -m "feat(pcb-v2): footprint tact CAX C39832249 (4.5x4.5, 4 patas)"
```

---

### Task 2: Esquemático — `gen_sch.py` a 12 entradas, sin OLED

**Files:**
- Modify: `scripts/gen_sch.py`

- [ ] **Step 1: Reemplazar el mapeo de nets y el bucle de switches.** En `gen_sch.py`:

Reemplazar las constantes `J1_NETS`, `J2_NETS`, `J3_NETS` por:
```python
# 12 entradas (sin OLED). Cada SWn a su pin de header segun el contrato.
J1_NETS = ["GND", "GND", None, None, None, None, None, None,
           "SW4", "SW2", "SW3", "SW1", "SW11", "SW9"]
J2_NETS = ["GND", None, None, None, None, None, None, "SW8",
           "SW7", None, "SW6", "SW5", "SW12", "SW10"]
# J1.9=D0=SW4, J1.10=D1=SW2, J1.11=D2=SW3, J1.12=D3=SW1, J1.13=D5=SW11, J1.14=D8=SW9
# J2.8=A1=SW8, J2.9=A0=SW7, J2.11=D12=SW6, J2.12=D11=SW5, J2.13=D10=SW12, J2.14=D9=SW10
# J2.2=+3V3 y SDA/SCL/J3 eliminados (sin OLED).
```

Reemplazar el bucle `for k in range(8): ... SW%d` por uno de 12 con el footprint correcto (los tact usan el footprint nuevo):
```python
SW_FP_MX   = "redbearpad:SW_Redragon_LowProfile_PCB_1.00u"
SW_FP_TACT = "redbearpad:SW_Tact_CAX_4.5x4.5"
TACT_REFS = {"SW11", "SW12"}
for k in range(12):
    ref = "SW%d" % (k + 1)
    x, y = 63.5, 25.4 + 15.24 * k
    fp = SW_FP_TACT if ref in TACT_REFS else SW_FP_MX
    body.append(sym_instance("Switch:SW_Push", ref, "Tact_CAX" if ref in TACT_REFS else "Redragon_LP",
                             fp, x, y, ["1", "2"]))
    for num, net in (("1", ref), ("2", "GND")):
        px, py = sw_pins[num]
        body.append(glabel(net, x + px, y - py, left=px < 0))
```

Eliminar la línea `place_conn("J3", ...)` (OLED) por completo.

- [ ] **Step 2: Regenerar el esquemático**

```powershell
$py = "C:\Users\sebastian.duarte\AppData\Local\Programs\KiCad\9.0\bin\python.exe"
& $py C:\redbearpad\gamepad-pcb\scripts\gen_sch.py
```
Esperado: `Escrito ...redbearpad.kicad_sch`, sin excepción.

- [ ] **Step 3: ERC**

```powershell
$cli = "C:\Users\sebastian.duarte\AppData\Local\Programs\KiCad\9.0\bin\kicad-cli.exe"
& $cli sch erc --exit-code-violations C:\redbearpad\gamepad-pcb\redbearpad.kicad_sch
```
Esperado: exit 0 (sin violaciones). Pines no usados de J1/J2 deben tener no_connect/label; si ERC marca "unconnected", revisar el mapeo `None`.

- [ ] **Step 4: Exportar netlist**

```powershell
$cli = "C:\Users\sebastian.duarte\AppData\Local\Programs\KiCad\9.0\bin\kicad-cli.exe"
& $cli sch export netlist --format kicadsexpr -o C:\redbearpad\gamepad-pcb\redbearpad.net C:\redbearpad\gamepad-pcb\redbearpad.kicad_sch
```
Esperado: `redbearpad.net` regenerado con nets SW1..SW12 + GND, sin SDA/SCL/+3V3/J3.

- [ ] **Step 5: Commit**

```powershell
git -C C:\redbearpad\gamepad-pcb add scripts/gen_sch.py redbearpad.kicad_sch redbearpad.net
git -C C:\redbearpad\gamepad-pcb commit -m "feat(pcb-v2): esquematico a 12 entradas (10 MX + 2 tact), OLED fuera"
```

---

### Task 3: Contrato del netlist — `verify_netlist.py` a 12 entradas

**Files:**
- Modify: `scripts/verify_netlist.py`

- [ ] **Step 1: Reemplazar el dict `EXPECTED`** por:
```python
EXPECTED = {
    "GND": {("J1", "1"), ("J1", "2"), ("J2", "1"),
            ("SW1", "2"), ("SW2", "2"), ("SW3", "2"), ("SW4", "2"),
            ("SW5", "2"), ("SW6", "2"), ("SW7", "2"), ("SW8", "2"),
            ("SW9", "2"), ("SW10", "2"), ("SW11", "2"), ("SW12", "2")},
    "SW1":  {("SW1", "1"),  ("J1", "12")},
    "SW2":  {("SW2", "1"),  ("J1", "10")},
    "SW3":  {("SW3", "1"),  ("J1", "11")},
    "SW4":  {("SW4", "1"),  ("J1", "9")},
    "SW5":  {("SW5", "1"),  ("J2", "12")},
    "SW6":  {("SW6", "1"),  ("J2", "11")},
    "SW7":  {("SW7", "1"),  ("J2", "9")},
    "SW8":  {("SW8", "1"),  ("J2", "8")},
    "SW9":  {("SW9", "1"),  ("J1", "14")},
    "SW10": {("SW10", "1"), ("J2", "14")},
    "SW11": {("SW11", "1"), ("J1", "13")},
    "SW12": {("SW12", "1"), ("J2", "13")},
}
```

- [ ] **Step 2: Correr el verificador**

```powershell
python C:\redbearpad\gamepad-pcb\scripts\verify_netlist.py
```
Esperado: `NETLIST OK`, exit 0. Si da MISMATCH, hay desalineación entre `gen_sch.py` (Task 2) y este contrato — corregir el que esté mal según la tabla de mapeo.

- [ ] **Step 3: Commit**

```powershell
git -C C:\redbearpad\gamepad-pcb add scripts/verify_netlist.py
git -C C:\redbearpad\gamepad-pcb commit -m "feat(pcb-v2): contrato de netlist a 12 entradas"
```

---

### Task 4: Placement — `gen_pcb.py` PLACE + footprints, sin OLED

**Files:**
- Modify: `scripts/gen_pcb.py`

- [ ] **Step 1: Agregar el footprint tact y actualizar `PLACE`.** En `gen_pcb.py`, tras `SW_FP = (...)` agregar:
```python
TACT_FP = (LOCAL_LIB, "SW_Tact_CAX_4.5x4.5")
```
Reemplazar el dict `PLACE` por (12 switches en sus posiciones; SW11/SW12 con TACT_FP; sin J3):
```python
PLACE = {
    "SW1":  (SW_FP, 32, 32, False), "SW2":  (SW_FP, 32, 48, False),
    "SW3":  (SW_FP, 16, 48, False), "SW4":  (SW_FP, 48, 48, False),
    "SW5":  (SW_FP, 64, 32, False), "SW6":  (SW_FP, 80, 32, False),
    "SW7":  (SW_FP, 64, 48, False), "SW8":  (SW_FP, 80, 48, False),
    "SW9":  (SW_FP, 16, 16, False), "SW10": (SW_FP, 80, 16, False),
    "SW11": (TACT_FP, 32, 16, False), "SW12": (TACT_FP, 64, 16, False),
    "J1": (S14, 40.38, 1.667, True),
    "J2": (S14, 55.62, 1.667, True),
    "H1": (HOLE, 4, 4, False), "H2": (HOLE, 92, 4, False),
    "H3": (HOLE, 4, 60, False), "H4": (HOLE, 92, 60, False),
}
```
Eliminar la tupla `S04` y la línea `"J3": (S04, ...)`.

- [ ] **Step 2: Quitar asserts y silk del OLED.** Borrar los asserts `pad_at("J3", ...)`. En el bloque de NPTH keepouts, los tact (SW11/SW12) **no** llevan el keepout de 2.6 mm del poste central (no tienen poste); ajustar el bucle:
```python
for ref, (_, x, y, _) in PLACE.items():
    if ref in ("SW11", "SW12"):
        continue                         # tact: sin agujero central grande
    if ref.startswith("SW"):
        npth_keepout(x, y, 2.6)
    elif ref.startswith("H"):
        npth_keepout(x, y, 1.95)
```
Borrar el bloque de silk del OLED (las líneas `for lbl, py in (("SDA"...`).

- [ ] **Step 3: Reemplazar el bloque `TRACKS` por uno vacío temporal** para poder generar y ver el ratsnest antes de rutear:
```python
TRACKS = []  # se rutea en la Task 6
```

- [ ] **Step 4: Generar el PCB (sin pistas todavía)**

```powershell
$py = "C:\Users\sebastian.duarte\AppData\Local\Programs\KiCad\9.0\bin\python.exe"
& $py C:\redbearpad\gamepad-pcb\scripts\gen_pcb.py
```
Esperado: `PCB escrita: ...redbearpad.kicad_pcb` sin AssertionError (los asserts de pads de SW/J deben pasar con las posiciones nuevas; si un assert de SW1/SW8 falla, actualizar sus coordenadas esperadas a las nuevas posiciones).

- [ ] **Step 5: Commit (placement, aún sin rutear)**

```powershell
git -C C:\redbearpad\gamepad-pcb add scripts/gen_pcb.py redbearpad.kicad_pcb
git -C C:\redbearpad\gamepad-pcb commit -m "feat(pcb-v2): placement de 12 footprints, OLED fuera (sin pistas aun)"
```

---

### Task 5: Firmware XInput a 12 botones

**Files:**
- Modify: `firmware/redbearpad_xinput/redbearpad_xinput.ino`

- [ ] **Step 1: Reemplazar el mapeo y la lógica** del sketch por la versión de 12 entradas (pines según el contrato; orden del array por función):

```cpp
#include <XInput.h>

// PIN_BOTON en orden de funcion. Pines segun el contrato del PCB v2.
// 0:Up(D3) 1:Down(D1) 2:Left(D2) 3:Right(D0) 4:A(D11) 5:B(D12) 6:X(A0) 7:Y(A1)
// 8:L(D8) 9:R(D9) 10:Select(D5) 11:Start(D10)
const uint8_t NUM_BOTONES = 12;
const uint8_t PIN_BOTON[NUM_BOTONES] = { 3, 1, 2, 0, 11, 12, A0, A1, 8, 9, 5, 10 };
const uint8_t IDX_UP = 0, IDX_DOWN = 1, IDX_LEFT = 2, IDX_RIGHT = 3;

bool estadoPrev[NUM_BOTONES];
uint8_t integrador[NUM_BOTONES];
uint32_t tUltimoSample = 0;
const uint8_t SAMPLE_MS = 1;
const uint8_t INTEGRADOR_MAX = 12;

void setup() {
  for (uint8_t i = 0; i < NUM_BOTONES; i++) {
    pinMode(PIN_BOTON[i], INPUT_PULLUP);
    estadoPrev[i] = false;
    integrador[i] = 0;
  }
  pinMode(LED_BUILTIN, OUTPUT);
  XInput.setAutoSend(false);
  XInput.begin();
}

void loop() {
  uint32_t ahora = millis();
  bool huboCambio = false;

  if (ahora - tUltimoSample >= SAMPLE_MS) {
    tUltimoSample = ahora;
    for (uint8_t i = 0; i < NUM_BOTONES; i++) {
      bool leido = (digitalRead(PIN_BOTON[i]) == LOW);
      if (leido) { if (integrador[i] < INTEGRADOR_MAX) integrador[i]++; }
      else       { if (integrador[i] > 0)              integrador[i]--; }
      bool nuevo = estadoPrev[i];
      if (integrador[i] >= INTEGRADOR_MAX) nuevo = true;
      else if (integrador[i] == 0)         nuevo = false;
      if (nuevo != estadoPrev[i]) { estadoPrev[i] = nuevo; huboCambio = true; }
    }
  }

  if (huboCambio) {
    bool up = estadoPrev[IDX_UP], down = estadoPrev[IDX_DOWN];
    bool left = estadoPrev[IDX_LEFT], right = estadoPrev[IDX_RIGHT];
    XInput.setJoystick(JOY_LEFT, up, down, left, right);
    XInput.setDpad(up, down, left, right);
    XInput.setButton(BUTTON_A,     estadoPrev[4]);
    XInput.setButton(BUTTON_B,     estadoPrev[5]);
    XInput.setButton(BUTTON_X,     estadoPrev[6]);
    XInput.setButton(BUTTON_Y,     estadoPrev[7]);
    XInput.setButton(BUTTON_LB,    estadoPrev[8]);   // L
    XInput.setButton(BUTTON_RB,    estadoPrev[9]);   // R
    XInput.setButton(BUTTON_BACK,  estadoPrev[10]);  // Select
    XInput.setButton(BUTTON_START, estadoPrev[11]);  // Start
    XInput.send();
  }

  digitalWrite(LED_BUILTIN, (millis() / 500) % 2);
}
```

- [ ] **Step 2: Compilar**

```powershell
& "C:\redbearpad\tools\arduino-cli\arduino-cli.exe" compile --clean -b xinput:avr:micro C:\redbearpad\gamepad-pcb\firmware\redbearpad_xinput
```
Esperado: exit 0, `Sketch uses ... bytes`. Si falla por un BUTTON_* inexistente, revisar los nombres en `XInput.h` (BUTTON_LB/RB/BACK/START existen).

- [ ] **Step 3: Commit**

```powershell
git -C C:\redbearpad\gamepad-pcb add firmware/redbearpad_xinput/redbearpad_xinput.ino
git -C C:\redbearpad\gamepad-pcb commit -m "feat(pcb-v2): firmware XInput a 12 botones (mapeo contrato v2)"
```

---

### Task 6: Ruteo del PCB (iterativo) + DRC + gerbers

Esta es la tarea de diseño-en-el-lazo. Objetivo: pistas para las 12 nets SWn (cada SWn.1 → su pin de header) en 2 capas, **DRC 0**. Las nets de switch terminan en el pad de J1/J2 indicado en el contrato; GND lo resuelven las zonas (pad 2 de cada switch + J1.1/2, J2.1).

**Files:**
- Modify: `scripts/gen_pcb.py` (lista `TRACKS`)

- [ ] **Step 1: Coordenadas de pads de header destino.** Imprimir las posiciones reales de los pads de J1/J2 para rutear hacia ellas:
```powershell
$py = "C:\Users\sebastian.duarte\AppData\Local\Programs\KiCad\9.0\bin\python.exe"
& $py -c "import pcbnew; b=pcbnew.LoadBoard(r'C:\redbearpad\gamepad-pcb\redbearpad.kicad_pcb'); [print(f.GetReference(), [(p.GetPadName(), round(p.GetPosition().x/1e6,3), round(p.GetPosition().y/1e6,3)) for p in f.Pads()]) for f in b.GetFootprints() if f.GetReference() in ('J1','J2')]"
```
Anotar (pad, x, y) de cada pin de J1/J2 destino del contrato. Cada SWn.1 sale del pad del switch (centro±(3.8,3.8)/(0,6.5)) hacia su pin.

- [ ] **Step 2: Rutear net por net en `TRACKS`.** Para cada SWn, añadir una entrada `(net, capa, ancho, [puntos])` con una polilínea desde el pad del switch hasta el pad del header destino, en F.Cu o B.Cu, sin cruzar otras pistas de la misma capa. Patrón de referencia (de v1): pistas de 0.25 mm, usar B.Cu para cruces, entrar a los peines de J1/J2 por corredores verticales escalonados (ver comentarios de v1 en el git anterior de `gen_pcb.py`). Regenerar tras cada cambio:
```powershell
& $py C:\redbearpad\gamepad-pcb\scripts\gen_pcb.py
```

- [ ] **Step 3: DRC tras cada iteración**
```powershell
$cli = "C:\Users\sebastian.duarte\AppData\Local\Programs\KiCad\9.0\bin\kicad-cli.exe"
& $cli pcb drc --exit-code-violations --schematic-parity C:\redbearpad\gamepad-pcb\redbearpad.kicad_pcb
```
Esperado al terminar: exit 0 (0 violaciones, 0 unconnected). Iterar Steps 2–3 hasta DRC limpio. Si quedan nets sin conectar, el reporte las nombra: rutear esas. **No** avanzar con violaciones.

- [ ] **Step 4: Regenerar gerbers de fabricación**
```powershell
$cli = "C:\Users\sebastian.duarte\AppData\Local\Programs\KiCad\9.0\bin\kicad-cli.exe"
$fab = "C:\redbearpad\gamepad-pcb\fabrication\gerbers"
& $cli pcb export gerbers -o $fab C:\redbearpad\gamepad-pcb\redbearpad.kicad_pcb
& $cli pcb export drill -o $fab C:\redbearpad\gamepad-pcb\redbearpad.kicad_pcb
```
Esperado: gerbers + drill regenerados sin error. (Regenerar el zip JLCPCB es opcional y manual.)

- [ ] **Step 5: Commit**
```powershell
git -C C:\redbearpad\gamepad-pcb add scripts/gen_pcb.py redbearpad.kicad_pcb fabrication/
git -C C:\redbearpad\gamepad-pcb commit -m "feat(pcb-v2): ruteo de 12 nets, DRC limpio, gerbers regenerados"
```

---

### Task 7: README v2 + cierre

**Files:**
- Modify: `README.md`
- Modify: `scripts/verify_netlist.py` (ya hecho en Task 3, solo confirmar)

- [ ] **Step 1: Actualizar `README.md`** — cambiar la descripción de "8 switches + OLED" a "12 entradas (10 switches Redragon + 2 tact CAX), sin OLED, mando XInput"; actualizar la tabla de conexiones al contrato v2; mencionar el firmware `redbearpad_xinput`.

- [ ] **Step 2: Verificación final integral**
```powershell
$py = "C:\Users\sebastian.duarte\AppData\Local\Programs\KiCad\9.0\bin\python.exe"
$cli = "C:\Users\sebastian.duarte\AppData\Local\Programs\KiCad\9.0\bin\kicad-cli.exe"
python C:\redbearpad\gamepad-pcb\scripts\verify_netlist.py
& $cli sch erc --exit-code-violations C:\redbearpad\gamepad-pcb\redbearpad.kicad_sch
& $cli pcb drc --exit-code-violations --schematic-parity C:\redbearpad\gamepad-pcb\redbearpad.kicad_pcb
```
Esperado: `NETLIST OK` + ERC exit 0 + DRC exit 0.

- [ ] **Step 3: Commit**
```powershell
git -C C:\redbearpad\gamepad-pcb add README.md
git -C C:\redbearpad\gamepad-pcb commit -m "docs(pcb-v2): README del mando XInput de 12 botones"
```

---

## Verificación contra la spec

- Board 96×64, holes, Blend Micro headers, OLED fuera → Task 4 (PLACE), Task 2 (nets).
- 12 entradas (10 MX + 2 tact CAX) con posiciones/mapeo → Tasks 1, 2, 4.
- Asignación de pines limpia (sin D6/D7/D13/SPI) → contrato + Task 2/3.
- verify_netlist contrato 12 → Task 3.
- Ruteo + ERC/DRC 0 + gerbers → Task 6.
- Firmware XInput 12 botones → Task 5.
- Footprint tact CAX → Task 1.

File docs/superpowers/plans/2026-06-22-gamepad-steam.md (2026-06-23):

# Firmware Gamepad HID (Steam) — Plan de Implementación

> **For agentic workers:** REQUIRED SUB-SKILL: Use superpowers:subagent-driven-development (recommended) or superpowers:executing-plans to implement this plan task-by-task. Steps use checkbox (`- [ ]`) syntax for tracking.

**Goal:** Sketch `redbearpad_gamepad.ino` que hace que el RedBearPad enumere como gamepad HID (cruceta + 4 botones) reconocible por Steam.

**Architecture:** Sketch nuevo e independiente del keypad. Usa `Gamepad` de HID-Project. Reutiliza el debounce por integrador + muestreo fijo. Cada ciclo: filtra los 8 switches, combina 4 en la cruceta (hat, con diagonales) y mapea 4 a botones 1-4; envía el reporte solo al cambiar. OLED opcional muestra el estado.

**Tech Stack:** Arduino (ATmega32U4), HID-Project (Gamepad), Adafruit SSD1306/GFX, arduino-cli.

**Spec:** `docs/superpowers/specs/2026-06-22-gamepad-steam-design.md`

**Entorno (Windows / PowerShell):**
- arduino-cli: `C:\redbearpad\tools\arduino-cli\arduino-cli.exe`
- Repo: `C:\redbearpad\gamepad-pcb` (git, rama `implementacion`)
- FQBN: **`redbearlab:avr:blendmicro8`** (8 MHz — NUNCA 16 MHz; es overclock fuera de spec a 3.3 V).
- Librerías ya instaladas: HID-Project, Adafruit SSD1306, Adafruit GFX.

**Nota de verificación:** No hay framework de tests en el dispositivo. La verificación de cada tarea es: (a) **compilación limpia** con arduino-cli (lo hace el agente), y donde aplique (b) un **auto-test on-device** que imprime PASS/FAIL por serie, y (c) checks físicos en `joy.cpl`/Steam que ejecuta el usuario con la placa.

**Mapeo (índices dentro de `PIN_BOTON` / `estadoPrev`, 0-based):**

| idx | Switch | Pin | Rol |
|---|---|---|---|
| 0 | SW1 | 5 (D5)  | Botón 1 |
| 1 | SW2 | 8 (D8)  | Cruceta ARRIBA |
| 2 | SW3 | 9 (D9)  | Cruceta IZQUIERDA |
| 3 | SW4 | 10 (D10)| Cruceta ABAJO |
| 4 | SW5 | 11 (D11)| Cruceta DERECHA |
| 5 | SW6 | 12 (D12)| Botón 2 |
| 6 | SW7 | A0 | Botón 3 |
| 7 | SW8 | A1 | Botón 4 |

---

### Task 1: Baseline limpia — commitear cambios pendientes del keypad

El keypad tiene cambios sin commitear (scanner I2C + detección honesta de OLED) que se reutilizan aquí. Se guardan primero para partir de un árbol limpio.

**Files:**
- Commit: `firmware/redbearpad_keypad/redbearpad_keypad.ino` (ya modificado, sin commitear)

- [ ] **Step 1: Revisar el diff pendiente**

```powershell
git -C C:\redbearpad\gamepad-pcb diff --stat
```
Esperado: un archivo cambiado, `firmware/redbearpad_keypad/redbearpad_keypad.ino`.

- [ ] **Step 2: Commit**

```powershell
git -C C:\redbearpad\gamepad-pcb add firmware/redbearpad_keypad/redbearpad_keypad.ino
git -C C:\redbearpad\gamepad-pcb commit -m "feat(keypad): scanner I2C y deteccion honesta de OLED (probe ACK antes de begin)"
```
Esperado: commit creado. (No se hace `git push`: el repo no tiene remoto.)

---

### Task 2: Firmware del gamepad (cruceta + botones + diagnósticos)

Crea el sketch completo y funcional como mando (sin dibujo de OLED todavía). Incluye un auto-test de la lógica de cruceta que corre en `setup()`.

**Files:**
- Create: `firmware/redbearpad_gamepad/redbearpad_gamepad.ino` (la carpeta ya existe)

- [ ] **Step 1: Crear el sketch completo**

Contenido íntegro de `C:\redbearpad\gamepad-pcb\firmware\redbearpad_gamepad\redbearpad_gamepad.ino`:

```cpp
/*
 * RedBearPad - Gamepad USB HID (8 switches) para Steam
 * Placa: RedBearLab Blend Micro V1.0 (ATmega32U4, core redbearlab:avr).
 * USAR SIEMPRE 8 MHz (blendmicro8): 16 MHz es overclock fuera de spec a 3.3 V.
 *
 * Enumera como gamepad HID generico. En Windows aparece en joy.cpl; en Steam se
 * configura con Steam Input.
 *
 * Mapeo (fijado por la PCB):
 *   Cruceta: SW2=Arriba(D8)  SW3=Izq(D9)  SW4=Abajo(D10)  SW5=Der(D11)
 *   Botones: SW1=B1(D5)  SW6=B2(D12)  SW7=B3(A0)  SW8=B4(A1)
 *
 * Librerias: HID-Project (NicoHood), Adafruit SSD1306, Adafruit GFX.
 */
#include <HID-Project.h>
#include <Wire.h>
#include <Adafruit_GFX.h>
#include <Adafruit_SSD1306.h>

// ----- Switches: un pin por boton, a GND, pull-up interno (activo en LOW) -----
const uint8_t NUM_BOTONES = 8;
const uint8_t PIN_BOTON[NUM_BOTONES] = { 5, 8, 9, 10, 11, 12, A0, A1 };  // SW1..SW8
// Indices dentro de PIN_BOTON / estadoPrev: 0=SW1 1=SW2 2=SW3 3=SW4 4=SW5 5=SW6 6=SW7 7=SW8
const uint8_t IDX_UP = 1, IDX_LEFT = 2, IDX_DOWN = 3, IDX_RIGHT = 4;  // cruceta
const uint8_t IDX_BTN[4] = { 0, 5, 6, 7 };  // SW1,SW6,SW7,SW8 -> botones gamepad 1..4
const char* const ETIQUETA[NUM_BOTONES] = { "B1", "Up", "Lt", "Dn", "Rt", "B2", "B3", "B4" };

// ----- Debounce por integrador con histeresis, muestreo a intervalo FIJO -----
bool estadoPrev[NUM_BOTONES];
uint8_t integrador[NUM_BOTONES];
uint32_t tUltimoSample = 0;
const uint8_t SAMPLE_MS = 1;
const uint8_t INTEGRADOR_MAX = 12;

// ----- OLED 128x32 por I2C (opcional) -----
#define OLED_ANCHO 128
#define OLED_ALTO  32
#define OLED_RESET -1
Adafruit_SSD1306 oled(OLED_ANCHO, OLED_ALTO, &Wire, OLED_RESET);
bool oledOk = false;

// Combina las 4 direcciones en un valor de hat (incluye diagonales).
int8_t calcularDpad(bool up, bool down, bool left, bool right) {
  if (up && down)    { up = false; down = false; }    // opuestos se cancelan
  if (left && right) { left = false; right = false; }
  if (up && right)   return GAMEPAD_DPAD_UP_RIGHT;
  if (up && left)    return GAMEPAD_DPAD_UP_LEFT;
  if (down && right) return GAMEPAD_DPAD_DOWN_RIGHT;
  if (down && left)  return GAMEPAD_DPAD_DOWN_LEFT;
  if (up)    return GAMEPAD_DPAD_UP;
  if (down)  return GAMEPAD_DPAD_DOWN;
  if (left)  return GAMEPAD_DPAD_LEFT;
  if (right) return GAMEPAD_DPAD_RIGHT;
  return GAMEPAD_DPAD_CENTERED;
}

// Auto-test de la logica de cruceta: corre una vez en setup, imprime PASS/FAIL.
void probarDpad() {
  struct Caso { bool u, d, l, r; int8_t esperado; };
  const Caso casos[] = {
    { 0,0,0,0, GAMEPAD_DPAD_CENTERED },
    { 1,0,0,0, GAMEPAD_DPAD_UP },
    { 0,1,0,0, GAMEPAD_DPAD_DOWN },
    { 0,0,1,0, GAMEPAD_DPAD_LEFT },
    { 0,0,0,1, GAMEPAD_DPAD_RIGHT },
    { 1,0,1,0, GAMEPAD_DPAD_UP_LEFT },
    { 1,0,0,1, GAMEPAD_DPAD_UP_RIGHT },
    { 0,1,1,0, GAMEPAD_DPAD_DOWN_LEFT },
    { 0,1,0,1, GAMEPAD_DPAD_DOWN_RIGHT },
    { 1,1,0,0, GAMEPAD_DPAD_CENTERED },   // arriba+abajo se cancelan
    { 0,0,1,1, GAMEPAD_DPAD_CENTERED },   // izq+der se cancelan
    { 1,1,1,1, GAMEPAD_DPAD_CENTERED },   // todo se cancela
  };
  uint8_t fallos = 0;
  for (uint8_t i = 0; i < sizeof(casos) / sizeof(casos[0]); i++) {
    int8_t got = calcularDpad(casos[i].u, casos[i].d, casos[i].l, casos[i].r);
    if (got != casos[i].esperado) {
      fallos++;
      Serial.print(F("  FAIL caso ")); Serial.print(i);
      Serial.print(F(" -> ")); Serial.print(got);
      Serial.print(F(" esperaba ")); Serial.println(casos[i].esperado);
    }
  }
  Serial.print(F("dpad self-test: "));
  Serial.println(fallos == 0 ? F("PASS") : F("FAIL"));
}

bool i2cResponde(uint8_t addr) {
  Wire.beginTransmission(addr);
  return (Wire.endTransmission() == 0);
}

void escanearI2C() {
  Serial.println(F("=== Escaneo I2C ==="));
  uint8_t n = 0;
  for (uint8_t a = 1; a < 127; a++) {
    if (i2cResponde(a)) {
      Serial.print(F("  dispositivo en 0x"));
      if (a < 16) Serial.print('0');
      Serial.println(a, HEX);
      n++;
    }
  }
  if (n == 0) Serial.println(F("  nada respondio -> revisar SDA/SCL/VCC/GND o el modulo OLED"));
}

void setup() {
  Serial.begin(115200);
  for (uint8_t i = 0; i < NUM_BOTONES; i++) {
    pinMode(PIN_BOTON[i], INPUT_PULLUP);
    estadoPrev[i] = false;
    integrador[i] = 0;
  }

  Wire.begin();
  Wire.setWireTimeout(25000 /*us*/, true /*resetea el bus al expirar*/);

  // Deteccion honesta de OLED: probar ACK por I2C antes de begin (Adafruit begin()
  // devuelve true aunque no haya pantalla). Probar 0x3C y, si falla, 0x3D.
  uint8_t oledAddr = 0;
  if (i2cResponde(0x3C))      oledAddr = 0x3C;
  else if (i2cResponde(0x3D)) oledAddr = 0x3D;
  oledOk = (oledAddr != 0) && oled.begin(SSD1306_SWITCHCAPVCC, oledAddr);
  if (oledOk) { oled.clearDisplay(); oled.display(); }  // sin dibujo aun

  uint32_t t0 = millis();
  while (!Serial && millis() - t0 < 3000) { /* espera hasta 3 s al PC */ }

  Serial.println(F("=== RedBearPad gamepad - autodiagnostico de pines ==="));
  for (uint8_t i = 0; i < NUM_BOTONES; i++) {
    bool low = (digitalRead(PIN_BOTON[i]) == LOW);
    Serial.print(ETIQUETA[i]); Serial.print(F(" (pin "));
    Serial.print(PIN_BOTON[i]); Serial.print(F("): "));
    Serial.println(low ? F("LOW <-- CLAVADO sin pulsar!") : F("HIGH ok"));
  }
  escanearI2C();
  Serial.print(F("OLED: "));
  Serial.println(oledOk ? F("detectada") : F("NO detectada (ver escaneo I2C)"));
  probarDpad();

  Gamepad.begin();
  Serial.println(F("Gamepad HID iniciado."));
}

void loop() {
  uint32_t ahora = millis();
  bool huboCambio = false;

  if (ahora - tUltimoSample >= SAMPLE_MS) {
    tUltimoSample = ahora;
    for (uint8_t i = 0; i < NUM_BOTONES; i++) {
      bool leido = (digitalRead(PIN_BOTON[i]) == LOW);
      if (leido) { if (integrador[i] < INTEGRADOR_MAX) integrador[i]++; }
      else       { if (integrador[i] > 0)              integrador[i]--; }
      bool nuevo = estadoPrev[i];
      if (integrador[i] >= INTEGRADOR_MAX) nuevo = true;
      else if (integrador[i] == 0)         nuevo = false;
      if (nuevo != estadoPrev[i]) {
        estadoPrev[i] = nuevo;
        huboCambio = true;
      }
    }
  }

  if (huboCambio) {
    int8_t dpad = calcularDpad(estadoPrev[IDX_UP], estadoPrev[IDX_DOWN],
                               estadoPrev[IDX_LEFT], estadoPrev[IDX_RIGHT]);
    Gamepad.dPad1(dpad);
    for (uint8_t b = 0; b < 4; b++) {
      if (estadoPrev[IDX_BTN[b]]) Gamepad.press(b + 1);
      else                        Gamepad.release(b + 1);
    }
    Gamepad.write();

    Serial.print(F("dpad=")); Serial.print((int)dpad);
    Serial.print(F(" botones="));
    for (uint8_t b = 0; b < 4; b++) Serial.print(estadoPrev[IDX_BTN[b]] ? '1' : '0');
    Serial.println();
  }
}
```

- [ ] **Step 2: Compilar (verificación del agente)**

```powershell
$cli = "C:\redbearpad\tools\arduino-cli\arduino-cli.exe"
& $cli compile --clean -b redbearlab:avr:blendmicro8 C:\redbearpad\gamepad-pcb\firmware\redbearpad_gamepad
```
Esperado: termina con `Sketch uses ... bytes` y exit code 0. Si falla por una librería no encontrada, instalar: `& $cli lib install "HID-Project" "Adafruit SSD1306" "Adafruit GFX Library"`.

- [ ] **Step 3: Verificación en hardware (usuario)**

Subir desde el IDE de Arduino (placa **Blend Micro 3.3V/8MHz**), abrir Monitor Serie a 115200 y pulsar reset. Esperado al arranque:
- `dpad self-test: PASS`
- 8 líneas `... HIGH ok`
- Al pulsar switches: líneas `dpad=N botones=XXXX` con el valor correcto (p.ej. solo Up → `dpad=1`; Up+Lt → `dpad=8`; SW1 → `botones=1000`).

Si `dpad self-test: FAIL`, hay un error en `calcularDpad` — revisar contra la tabla de `probarDpad` antes de seguir.

- [ ] **Step 4: Commit**

```powershell
git -C C:\redbearpad\gamepad-pcb add firmware/redbearpad_gamepad/redbearpad_gamepad.ino
git -C C:\redbearpad\gamepad-pcb commit -m "feat(gamepad): firmware HID con cruceta (diagonales) y 4 botones"
```

---

### Task 3: Pantalla OLED con estado del mando (redibujo solo al cambiar)

Añade el dibujo del estado del gamepad, redibujando únicamente cuando cambia algo (elimina el parpadeo del refresco periódico).

**Files:**
- Modify: `firmware/redbearpad_gamepad/redbearpad_gamepad.ino`

- [ ] **Step 1: Añadir la función `dibujarPantalla()`**

Insertar esta función justo **antes** de `void setup() {`:

```cpp
// Dibuja el estado del mando: direccion de la cruceta + botones 1..4 (resaltados).
void dibujarPantalla() {
  oled.clearDisplay();
  oled.setTextSize(1);
  oled.setTextColor(SSD1306_WHITE);
  oled.setCursor(0, 0);
  oled.println(F("RedBearPad gamepad"));

  int8_t d = calcularDpad(estadoPrev[IDX_UP], estadoPrev[IDX_DOWN],
                          estadoPrev[IDX_LEFT], estadoPrev[IDX_RIGHT]);
  const char* dir = "centro";
  switch (d) {
    case GAMEPAD_DPAD_UP:         dir = "arriba";  break;
    case GAMEPAD_DPAD_DOWN:       dir = "abajo";   break;
    case GAMEPAD_DPAD_LEFT:       dir = "izq";     break;
    case GAMEPAD_DPAD_RIGHT:      dir = "der";     break;
    case GAMEPAD_DPAD_UP_LEFT:    dir = "arr-izq"; break;
    case GAMEPAD_DPAD_UP_RIGHT:   dir = "arr-der"; break;
    case GAMEPAD_DPAD_DOWN_LEFT:  dir = "aba-izq"; break;
    case GAMEPAD_DPAD_DOWN_RIGHT: dir = "aba-der"; break;
  }
  oled.setCursor(0, 12);
  oled.print(F("Dir: ")); oled.print(dir);

  for (uint8_t b = 0; b < 4; b++) {
    bool on = estadoPrev[IDX_BTN[b]];
    int16_t x = b * 32;
    if (on) {
      oled.fillRect(x, 23, 30, 9, SSD1306_WHITE);
      oled.setTextColor(SSD1306_BLACK);
    } else {
      oled.setTextColor(SSD1306_WHITE);
    }
    oled.setCursor(x + 2, 24);
    oled.print('B'); oled.print(b + 1);
  }
  oled.display();
}
```

- [ ] **Step 2: Dibujar la rejilla inicial en `setup()`**

Reemplazar en `setup()` la línea:
```cpp
  Serial.println(F("Gamepad HID iniciado."));
```
por:
```cpp
  Serial.println(F("Gamepad HID iniciado."));
  if (oledOk) dibujarPantalla();
```

- [ ] **Step 3: Redibujar al cambiar en `loop()`**

Reemplazar en `loop()` el bloque final:
```cpp
    Serial.print(F("dpad=")); Serial.print((int)dpad);
    Serial.print(F(" botones="));
    for (uint8_t b = 0; b < 4; b++) Serial.print(estadoPrev[IDX_BTN[b]] ? '1' : '0');
    Serial.println();
  }
}
```
por:
```cpp
    Serial.print(F("dpad=")); Serial.print((int)dpad);
    Serial.print(F(" botones="));
    for (uint8_t b = 0; b < 4; b++) Serial.print(estadoPrev[IDX_BTN[b]] ? '1' : '0');
    Serial.println();

    if (oledOk) dibujarPantalla();   // redibujo SOLO al cambiar -> sin parpadeo
  }
}
```

- [ ] **Step 4: Compilar**

```powershell
$cli = "C:\redbearpad\tools\arduino-cli\arduino-cli.exe"
& $cli compile --clean -b redbearlab:avr:blendmicro8 C:\redbearpad\gamepad-pcb\firmware\redbearpad_gamepad
```
Esperado: exit code 0, `Sketch uses ... bytes`.

- [ ] **Step 5: Commit**

```powershell
git -C C:\redbearpad\gamepad-pcb add firmware/redbearpad_gamepad/redbearpad_gamepad.ino
git -C C:\redbearpad\gamepad-pcb commit -m "feat(gamepad): OLED muestra cruceta y botones, redibujo solo al cambiar"
```

---

### Task 4: Verificación final y documentación

**Files:**
- Create: `firmware/redbearpad_gamepad/README.md`

- [ ] **Step 1: Compilar también para 16 MHz (sanity)**

```powershell
$cli = "C:\redbearpad\tools\arduino-cli\arduino-cli.exe"
& $cli compile --clean -b redbearlab:avr:blendmicro8  C:\redbearpad\gamepad-pcb\firmware\redbearpad_gamepad
& $cli compile --clean -b redbearlab:avr:blendmicro16 C:\redbearpad\gamepad-pcb\firmware\redbearpad_gamepad
```
Esperado: ambas compilan (exit 0). Recordatorio: para usar la placa, flashear **blendmicro8**.

- [ ] **Step 2: Escribir `firmware/redbearpad_gamepad/README.md`**

````markdown
# Firmware Gamepad — RedBearPad

Sketch `redbearpad_gamepad/redbearpad_gamepad.ino`: convierte la placa en un
**gamepad USB HID** con cruceta + 4 botones, para usar en Steam.

## Mapeo

| Switch | Rol gamepad |
|---|---|
| SW2 / SW3 / SW4 / SW5 | Cruceta Arriba / Izq / Abajo / Der (con diagonales) |
| SW1 | Botón 1 |
| SW6 | Botón 2 |
| SW7 | Botón 3 |
| SW8 | Botón 4 |

## Requisitos

- Core `redbearlab:avr` (repo `blend-micro-boards`).
- Librerías (Gestor de librerías): **HID-Project** (NicoHood), **Adafruit SSD1306**,
  **Adafruit GFX Library**.

## Compilar y subir

```powershell
$cli = "C:\redbearpad\tools\arduino-cli\arduino-cli.exe"
& $cli compile --fqbn redbearlab:avr:blendmicro8 firmware\redbearpad_gamepad
& $cli upload  --fqbn redbearlab:avr:blendmicro8 -p COM<N> firmware\redbearpad_gamepad
```

Usar **blendmicro8** (8 MHz). El 16 MHz es overclock fuera de spec a 3.3 V y causa
fallos erráticos.

## Probar

- **Windows:** `joy.cpl` → "RedBearPad" → mover cruceta y pulsar los 4 botones.
- **Monitor serie** (115200): al arrancar imprime `dpad self-test: PASS`, el
  autodiagnóstico de pines y el escaneo I2C; luego un eco `dpad=N botones=XXXX`.
- **Steam:** Configuración → Controlador → habilitar soporte de controles genéricos;
  configurar en Steam Input (la cruceta se puede asignar a d-pad o stick).
````

- [ ] **Step 3: Commit**

```powershell
git -C C:\redbearpad\gamepad-pcb add firmware/redbearpad_gamepad/README.md
git -C C:\redbearpad\gamepad-pcb commit -m "docs(gamepad): README de uso y configuracion en Steam"
```

---

## Verificación contra la spec

- Enumeración HID gamepad → Task 2 (`Gamepad.begin`).
- Lectura con integrador + muestreo fijo → Task 2 (reutilizado).
- Cruceta con diagonales → Task 2 (`calcularDpad` + `dPad1`), auto-test incluido.
- Botones 1-4 → Task 2 (`press`/`release` + `write`).
- OLED estado + redibujo solo al cambiar → Task 3.
- Diagnósticos (pines, I2C, eco serie) → Task 2.
- Verificación joy.cpl/Steam + 8 MHz → Tasks 3/4 + README.

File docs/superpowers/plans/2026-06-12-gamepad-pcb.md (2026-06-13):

# RedBearPad Gamepad PCB — Implementation Plan

> **For agentic workers:** REQUIRED SUB-SKILL: Use superpowers:subagent-driven-development (recommended) or superpowers:executing-plans to implement this plan task-by-task. Steps use checkbox (`- [ ]`) syntax for tracking.

**Goal:** Generar el proyecto KiCad 9 completo (esquemático + PCB ruteada + Gerbers JLCPCB) del gamepad de 8 botones con OLED para Blend Micro, según el spec `docs/superpowers/specs/2026-06-12-gamepad-pcb-design.md`.

**Architecture:** Todo se genera por script (Python) para que sea reproducible y verificable sin GUI: `gen_sch.py` produce el esquemático extrayendo símbolos de las librerías estándar de KiCad; el netlist exportado con `kicad-cli` alimenta a `gen_pcb.py` (API `pcbnew`) que coloca, rutea y rellena zonas. La verificación es ERC=0, DRC=0, 0 unconnected, más renders para revisión visual.

**Tech Stack:** KiCad 9.0.x (`kicad-cli.exe` + Python embebido con módulo `pcbnew`), PowerShell, git.

**Decisiones de plan (desviaciones conscientes del spec, mismo resultado):**
1. El "zócalo Blend Micro propio" se implementa como **dos footprints estándar `PinSocket_1x14_P2.54mm_Vertical`** (J1/J2) colocados en coordenadas exactas y volteados a la cara inferior, más serigrafía de orientación propia. Mismo resultado físico, menos riesgo que un footprint a mano.
2. La librería local se renombra `libs/footprints/` → `libs/redbearpad.pretty/` (convención KiCad para librerías de footprints).

---

## Datos maestros (de referencia para todas las tareas)

Coordenadas KiCad en mm, origen esquina superior izquierda de la placa, Y hacia abajo.

### Netlist objetivo

| Net | Nodos |
|---|---|
| GND | J1.1, J1.2, J2.1, J3.1, SW1.2 … SW8.2 |
| +3V3 | J2.2, J3.2 |
| SCL | J1.12, J3.3 |
| SDA | J1.11, J3.4 |
| SW1 | SW1.1, J1.13 |
| SW2 | SW2.1, J1.14 |
| SW3 | SW3.1, J2.14 |
| SW4 | SW4.1, J2.13 |
| SW5 | SW5.1, J2.12 |
| SW6 | SW6.1, J2.11 |
| SW7 | SW7.1, J2.9 |
| SW8 | SW8.1, J2.8 |

Pines sin conexión (no_connect en esquemático): J1.3–J1.10 (VIN, SS, CLK, MOSI, MISO, /RST, D0, D1), J2.3–J2.7 (AREF, A5–A2), J2.10 (D13).

El orden de pines de J1/J2 ya incorpora el **espejado por montaje en cara inferior**
(vista desde el frente de la placa, USB arriba):
J1 (columna x=40.38, pin1 arriba): GND, GND, VIN, SS, CLK, MOSI, MISO, /RST, D0, D1, D2/SDA, D3/SCL, D5, D8.
J2 (columna x=55.62, pin1 arriba): GND, V33, AREF, A5, A4, A3, A2, A1, A0, D13, D12, D11, D10, D9.

### Posiciones en placa

| Ref | Footprint | Posición (origen del footprint) | Cara | Notas |
|---|---|---|---|---|
| SW1 | `redbearpad:SW_Redragon_LowProfile_PCB_1.00u` | (16, 16) | F | pad1 en (+3.8,+3.8), pad2 en (0,+6.5) del origen |
| SW2 | ídem | (32, 32) | F | |
| SW3 | ídem | (16, 48) | F | |
| SW4 | ídem | (32, 48) | F | |
| SW5 | ídem | (48, 48) | F | |
| SW6 | ídem | (64, 32) | F | |
| SW7 | ídem | (80, 32) | F | |
| SW8 | ídem | (80, 48) | F | |
| J1 | `Connector_PinSocket_2.54mm:PinSocket_1x14_P2.54mm_Vertical` | (40.38, 1.667), pin n en y=1.667+2.54·(n−1) | **B** (flip) | fila izquierda Blend Micro |
| J2 | ídem | (55.62, 1.667) | **B** (flip) | fila derecha Blend Micro |
| J3 | `Connector_PinSocket_2.54mm:PinSocket_1x04_P2.54mm_Vertical` | (30, 9.7), pin n en y=9.7+2.54·(n−1) | F | OLED: GND, VCC, SCL, SDA |
| H1–H4 | `redbearpad:MountingHole_3.1mm` | (4,4), (92,4), (4,60), (92,60) | F | NPTH Ø3.1 |

Contorno: rect 96×64, esquinas r=1 (4 segmentos + 4 arcos en Edge.Cuts).
Zonas GND en F.Cu y B.Cu cubriendo toda la placa.
Pistas: señal 0.25 mm, +3V3 0.5 mm, clearance 0.2 mm (defaults KiCad).

### Rutas sugeridas (punto de partida; el criterio de éxito es DRC=0 y 0 unconnected, ajustar waypoints si hace falta)

Posiciones absolutas de pads señal de switches: pad1 = centro + (3.8, 3.8).

| Net | Capa | Waypoints (mm) |
|---|---|---|
| SW1 | F.Cu | (19.8,19.8) → (30,30) → (38.5,32.15) → (40.38,32.15) |
| SW2 | F.Cu | (35.8,35.8) → (39.2,34.69) → (40.38,34.687) |
| SW3 | F.Cu | (19.8,51.8) → (19.8,58) → (57.5,58) → (57.5,36.6) → (55.62,34.687) |
| SW4 | F.Cu | (35.8,51.8) → (43,46) → (43,38) → (53.5,33.5) → (55.62,32.147) |
| SW5 | F.Cu | (51.8,51.8) → (58.5,45) → (58.5,30.5) → (55.62,29.607) |
| SW6 | F.Cu | (67.8,35.8) → (62,29) → (57.5,27.5) → (55.62,27.067) |
| SW7 | F.Cu | (83.8,35.8) → (70,23) → (57.5,21.99) → (55.62,21.987) |
| SW8 | F.Cu | (83.8,51.8) → (75,40) → (62,19.45) → (55.62,19.447) |
| SDA | F.Cu | (30,17.32) → (36,22) → (38.5,27.07) → (40.38,27.067) |
| SCL | **B.Cu** | (30,14.78) → (34,20) → (38,29.61) → (40.38,29.607) |
| +3V3 (0.5mm) | F.Cu | (30,12.24) → (27.5,14) → (27.5,36.5) → (58.5,36.5) → (58.5,4.21) → (55.62,4.207) |

Notas de ruteo: nunca correr una pista vertical sobre una columna de pads (x=40.38 o x=55.62) — entrar a cada pad lateralmente desde x≈38.5 (J1, por la izquierda) o x≈57.5/58.5 (J2, por la derecha). El hueco entre pads adyacentes de una columna (pitch 2.54, pad Ø1.7) solo deja banda libre de ~0.84 mm: no cruzar columnas con pistas de 0.5 mm; la ruta de +3V3 rodea ambas columnas por el sur (y=36.5). GND no se rutea: lo conectan las zonas (si DRC reporta islas GND sin conectar, añadir vías de costura Ø0.6/0.3 donde haga falta).

---

### Task 1: Entorno y esqueleto del proyecto

**Files:**
- Create: `redbearpad.kicad_pro`
- Create: `fp-lib-table`
- Create: `.gitignore`
- Rename: `libs/footprints/` → `libs/redbearpad.pretty/`

- [ ] **Step 1: Verificar herramientas KiCad**

Run:
```powershell
& "C:\Program Files\KiCad\9.0\bin\kicad-cli.exe" version
& "C:\Program Files\KiCad\9.0\bin\python.exe" -c "import pcbnew; print(pcbnew.Version())"
```
Expected: ambas imprimen versión 9.0.x. Si la ruta no existe, localizar con
`Get-ChildItem 'C:\Program Files\KiCad' -Directory` y ajustar la ruta en TODOS los
comandos/scripts siguientes (definirla una vez como `$KICAD = "C:\Program Files\KiCad\<ver>\bin"`).

- [ ] **Step 2: Renombrar la librería local**

```powershell
git -C C:\redbearpad\gamepad-pcb mv libs/footprints libs/redbearpad.pretty
```

- [ ] **Step 3: Crear `redbearpad.kicad_pro`**

Contenido completo:
```json
{
  "board": { "design_settings": {}, "layer_presets": [], "viewports": [] },
  "boards": [],
  "cvpcb": { "equivalence_files": [] },
  "libraries": { "pinned_footprint_libs": [], "pinned_symbol_libs": [] },
  "meta": { "filename": "redbearpad.kicad_pro", "version": 3 },
  "net_settings": {
    "classes": [
      {
        "name": "Default",
        "clearance": 0.2, "track_width": 0.25,
        "via_diameter": 0.6, "via_drill": 0.3,
        "diff_pair_gap": 0.25, "diff_pair_via_gap": 0.25, "diff_pair_width": 0.2,
        "microvia_diameter": 0.3, "microvia_drill": 0.1,
        "bus_width": 12, "line_style": 0, "pcb_color": "rgba(0, 0, 0, 0.000)",
        "schematic_color": "rgba(0, 0, 0, 0.000)", "wire_width": 6
      }
    ],
    "meta": { "version": 4 }
  },
  "pcbnew": { "page_layout_descr_file": "" },
  "schematic": { "legacy_lib_dir": "", "legacy_lib_list": [] },
  "sheets": [],
  "text_variables": {}
}
```

- [ ] **Step 4: Crear `fp-lib-table`**

```
(fp_lib_table
  (version 7)
  (lib (name "redbearpad")(type "KiCad")(uri "${KIPRJMOD}/libs/redbearpad.pretty")(options "")(descr "Footprints locales RedBearPad"))
)
```

- [ ] **Step 5: Crear `.gitignore`**

```
*.kicad_prl
*-backups/
fp-info-cache
_autosave-*
~*.lck
```

- [ ] **Step 6: Commit**

```powershell
git -C C:\redbearpad\gamepad-pcb add -A
git -C C:\redbearpad\gamepad-pcb commit -m "Esqueleto del proyecto KiCad (pro, fp-lib-table, lib local)"
```

---

### Task 2: Footprint MountingHole_3.1mm

**Files:**
- Create: `libs/redbearpad.pretty/MountingHole_3.1mm.kicad_mod`

- [ ] **Step 1: Escribir el footprint**

Contenido completo:
```
(footprint "MountingHole_3.1mm"
	(version 20240108)
	(generator "manual")
	(layer "F.Cu")
	(descr "Perforacion de montaje M3, NPTH 3.1mm, segun REFERENCE_PCB.dxf")
	(attr exclude_from_pos_files exclude_from_bom)
	(property "Reference" "REF**"
		(at 0 -3 0)
		(layer "F.SilkS")
		(hide yes)
		(effects (font (size 1 1) (thickness 0.15)))
	)
	(property "Value" "MountingHole_3.1mm"
		(at 0 3 0)
		(layer "F.Fab")
		(hide yes)
		(effects (font (size 1 1) (thickness 0.15)))
	)
	(fp_circle (center 0 0) (end 1.8 0) (stroke (width 0.15) (type solid)) (fill none) (layer "F.CrtYd"))
	(pad "" np_thru_hole circle (at 0 0) (size 3.1 3.1) (drill 3.1) (layers "*.Cu" "*.Mask"))
)
```

- [ ] **Step 2: Test de carga (ambos footprints locales)**

```powershell
& "C:\Program Files\KiCad\9.0\bin\python.exe" -c @"
import pcbnew
lib = r'C:\redbearpad\gamepad-pcb\libs\redbearpad.pretty'
for name in ['MountingHole_3.1mm', 'SW_Redragon_LowProfile_PCB_1.00u']:
    fp = pcbnew.FootprintLoad(lib, name)
    assert fp is not None, name
    print(name, 'OK, pads:', fp.Pads().size())
"@
```
Expected: `MountingHole_3.1mm OK, pads: 1` y `SW_Redragon_LowProfile_PCB_1.00u OK, pads: 3`.

- [ ] **Step 3: Commit**

```powershell
git -C C:\redbearpad\gamepad-pcb add -A
git -C C:\redbearpad\gamepad-pcb commit -m "Footprint NPTH 3.1mm + verificacion de carga de libreria local"
```

---

### Task 3: Generador del esquemático + ERC

**Files:**
- Create: `scripts/gen_sch.py`
- Create (generado): `redbearpad.kicad_sch`

- [ ] **Step 1: Escribir `scripts/gen_sch.py`**

Código completo (si algún detalle del formato s-expression es rechazado por KiCad,
iterar hasta que el Step 2 y el ERC pasen — el formato de referencia se puede
inspeccionar guardando un esquemático mínimo desde la GUI de KiCad):

```python
"""Genera redbearpad.kicad_sch (formato KiCad 8, legible por KiCad 9).
Extrae los simbolos de las librerias estandar instaladas y conecta los pines
colocando global labels exactamente en el punto de conexion de cada pin
(sin wires). Pines no usados llevan no_connect.
"""
import os, re, uuid

KICAD_SYMS = r"C:\Program Files\KiCad\9.0\share\kicad\symbols"
HERE = os.path.dirname(os.path.abspath(__file__))
OUT = os.path.normpath(os.path.join(HERE, "..", "redbearpad.kicad_sch"))
ROOT_UUID = "f0a11111-2222-3333-4444-555566667777"

def U():
    return str(uuid.uuid4())

def balanced(text, start):
    depth = 0
    j = start
    while True:
        c = text[j]
        if c == "(":
            depth += 1
        elif c == ")":
            depth -= 1
            if depth == 0:
                return text[start:j + 1]
        j += 1

def extract_symbol(libfile, name):
    path = os.path.join(KICAD_SYMS, libfile)
    text = open(path, encoding="utf-8").read()
    i = text.index('(symbol "%s"' % name)
    block = balanced(text, i)
    nick = libfile.rsplit(".", 2)[0]
    return block.replace('(symbol "%s"' % name, '(symbol "%s:%s"' % (nick, name), 1)

def pin_map(sym_block):
    """num -> (x, y) punto de conexion en coords de simbolo (Y hacia arriba)."""
    pins = {}
    idx = 0
    while True:
        m = re.search(r"\(pin\s", sym_block[idx:])
        if not m:
            break
        blk = balanced(sym_block, idx + m.start())
        at = re.search(r"\(at\s+([-\d.]+)\s+([-\d.]+)", blk)
        num = re.search(r'\(number\s+"([^"]+)"', blk)
        pins[num.group(1)] = (float(at.group(1)), float(at.group(2)))
        idx = idx + m.start() + len(blk)
    return pins

def sym_instance(lib_id, ref, value, fp, x, y, pin_nums):
    pin_lines = "\n".join('    (pin "%s" (uuid "%s"))' % (n, U()) for n in pin_nums)
    return f"""  (symbol (lib_id "{lib_id}") (at {x} {y} 0) (unit 1)
    (exclude_from_sim no) (in_bom yes) (on_board yes) (dnp no)
    (uuid "{U()}")
    (property "Reference" "{ref}" (at {x} {y - 7.62} 0) (effects (font (size 1.27 1.27))))
    (property "Value" "{value}" (at {x} {y + 7.62} 0) (effects (font (size 1.27 1.27))))
    (property "Footprint" "{fp}" (at {x} {y} 0) (effects (font (size 1.27 1.27)) (hide yes)))
    (property "Datasheet" "" (at {x} {y} 0) (effects (font (size 1.27 1.27)) (hide yes)))
{pin_lines}
    (instances (project "redbearpad" (path "/{ROOT_UUID}" (reference "{ref}") (unit 1))))
  )"""

def glabel(net, x, y, left):
    ang = 180 if left else 0
    just = "(justify right)" if left else "(justify left)"
    return (f'  (global_label "{net}" (shape passive) (at {x} {y} {ang}) '
            f"(effects (font (size 1.27 1.27)) {just}) "
            f'(uuid "{U()}"))')

def no_connect(x, y):
    return f'  (no_connect (at {x} {y}) (uuid "{U()}"))'

sw_blk = extract_symbol("Switch.kicad_sym", "SW_Push")
c14_blk = extract_symbol("Connector_Generic.kicad_sym", "Conn_01x14")
c04_blk = extract_symbol("Connector_Generic.kicad_sym", "Conn_01x04")
sw_pins = pin_map(sw_blk)
c14_pins = pin_map(c14_blk)
c04_pins = pin_map(c04_blk)

J1_NETS = ["GND", "GND", None, None, None, None, None, None, None, None,
           "SDA", "SCL", "SW1", "SW2"]
J2_NETS = ["GND", "+3V3", None, None, None, None, None, "SW8", "SW7", None,
           "SW6", "SW5", "SW4", "SW3"]
J3_NETS = ["GND", "+3V3", "SCL", "SDA"]

body = []

def place_conn(ref, value, fp, lib_id, pins, nets, x, y):
    body.append(sym_instance(lib_id, ref, value, fp, x, y,
                             [str(n) for n in range(1, len(nets) + 1)]))
    for n, net in enumerate(nets, start=1):
        px, py = pins[str(n)]
        gx, gy = x + px, y - py
        if net is None:
            body.append(no_connect(gx, gy))
        else:
            body.append(glabel(net, gx, gy, left=px < 0))

for k in range(8):
    ref = "SW%d" % (k + 1)
    x, y = 63.5, 25.4 + 15.24 * k
    body.append(sym_instance("Switch:SW_Push", ref, "Redragon_LP",
                             "redbearpad:SW_Redragon_LowProfile_PCB_1.00u",
                             x, y, ["1", "2"]))
    for num, net in (("1", ref), ("2", "GND")):
        px, py = sw_pins[num]
        body.append(glabel(net, x + px, y - py, left=px < 0))

place_conn("J1", "BlendMicro_fila_izq",
           "Connector_PinSocket_2.54mm:PinSocket_1x14_P2.54mm_Vertical",
           "Connector_Generic:Conn_01x14", c14_pins, J1_NETS, 152.4, 63.5)
place_conn("J2", "BlendMicro_fila_der",
           "Connector_PinSocket_2.54mm:PinSocket_1x14_P2.54mm_Vertical",
           "Connector_Generic:Conn_01x14", c14_pins, J2_NETS, 203.2, 63.5)
place_conn("J3", "OLED_128x32_I2C",
           "Connector_PinSocket_2.54mm:PinSocket_1x04_P2.54mm_Vertical",
           "Connector_Generic:Conn_01x04", c04_pins, J3_NETS, 101.6, 152.4)

sch = f"""(kicad_sch (version 20231120) (generator "gen_sch")
  (uuid "{ROOT_UUID}")
  (paper "A3")
  (lib_symbols
{sw_blk}
{c14_blk}
{c04_blk}
  )
{chr(10).join(body)}
  (sheet_instances (path "/" (page "1")))
)
"""
with open(OUT, "w", encoding="utf-8") as f:
    f.write(sch)
print("Escrito", OUT)
```

- [ ] **Step 2: Generar y verificar que KiCad lo lee**

```powershell
& "C:\Program Files\KiCad\9.0\bin\python.exe" C:\redbearpad\gamepad-pcb\scripts\gen_sch.py
& "C:\Program Files\KiCad\9.0\bin\kicad-cli.exe" sch export netlist --output C:\redbearpad\gamepad-pcb\redbearpad.net C:\redbearpad\gamepad-pcb\redbearpad.kicad_sch
```
Expected: ambos sin error (el netlist se valida en la Task 4; aquí solo confirma
que el archivo es parseable).

- [ ] **Step 3: ERC limpio**

```powershell
& "C:\Program Files\KiCad\9.0\bin\kicad-cli.exe" sch erc --severity-error --exit-code-violations C:\redbearpad\gamepad-pcb\redbearpad.kicad_sch
```
Expected: exit code 0, "0 errors". Si reporta errores, leer el reporte, corregir
`gen_sch.py`, regenerar y repetir.

- [ ] **Step 4: Commit**

```powershell
git -C C:\redbearpad\gamepad-pcb add -A
git -C C:\redbearpad\gamepad-pcb commit -m "Esquematico generado por script, ERC limpio"
```

---

### Task 4: Verificación del netlist

**Files:**
- Create: `scripts/verify_netlist.py`
- Create (generado): `redbearpad.net`

- [ ] **Step 1: Escribir `scripts/verify_netlist.py`**

Código completo:
```python
"""Verifica que redbearpad.net contiene EXACTAMENTE las nets del spec."""
import os, re, sys

HERE = os.path.dirname(os.path.abspath(__file__))
NET = os.path.normpath(os.path.join(HERE, "..", "redbearpad.net"))

EXPECTED = {
    "GND": {("J1", "1"), ("J1", "2"), ("J2", "1"), ("J3", "1"),
            ("SW1", "2"), ("SW2", "2"), ("SW3", "2"), ("SW4", "2"),
            ("SW5", "2"), ("SW6", "2"), ("SW7", "2"), ("SW8", "2")},
    "+3V3": {("J2", "2"), ("J3", "2")},
    "SCL": {("J1", "12"), ("J3", "3")},
    "SDA": {("J1", "11"), ("J3", "4")},
    "SW1": {("SW1", "1"), ("J1", "13")},
    "SW2": {("SW2", "1"), ("J1", "14")},
    "SW3": {("SW3", "1"), ("J2", "14")},
    "SW4": {("SW4", "1"), ("J2", "13")},
    "SW5": {("SW5", "1"), ("J2", "12")},
    "SW6": {("SW6", "1"), ("J2", "11")},
    "SW7": {("SW7", "1"), ("J2", "9")},
    "SW8": {("SW8", "1"), ("J2", "8")},
}

def balanced(text, start):
    depth = 0
    j = start
    while True:
        if text[j] == "(":
            depth += 1
        elif text[j] == ")":
            depth -= 1
            if depth == 0:
                return text[start:j + 1]
        j += 1

text = open(NET, encoding="utf-8").read()
found = {}
idx = 0
while True:
    m = re.search(r"\(net\s+\(code", text[idx:])
    if not m:
        break
    blk = balanced(text, idx + m.start())
    name = re.search(r'\(name\s+"([^"]+)"\)', blk).group(1)
    nodes = set()
    for nm in re.finditer(r'\(node\s+\(ref\s+"([^"]+)"\)\s+\(pin\s+"([^"]+)"\)', blk):
        nodes.add((nm.group(1), nm.group(2)))
    if nodes:
        found[name.lstrip("/")] = nodes
    idx = idx + m.start() + len(blk)

ok = True
for net, nodes in EXPECTED.items():
    if found.get(net) != nodes:
        print("MISMATCH", net, "\n  esperado:", sorted(nodes),
              "\n  obtenido:", sorted(found.get(net, set())))
        ok = False
extra = set(found) - set(EXPECTED)
if extra:
    print("Nets extra con >1 nodo:", extra)
    # nets de un solo pin (pines NC) no aparecen aqui porque exigimos nodes
for net in extra:
    if len(found[net]) > 1:
        ok = False
print("NETLIST OK" if ok else "NETLIST CON ERRORES")
sys.exit(0 if ok else 1)
```

- [ ] **Step 2: Ejecutar**

```powershell
& "C:\Program Files\KiCad\9.0\bin\python.exe" C:\redbearpad\gamepad-pcb\scripts\verify_netlist.py
```
Expected: `NETLIST OK`, exit 0. Si falla, el error está en `gen_sch.py`
(orden de nets de J1/J2/J3) — corregir, regenerar, re-exportar netlist y repetir.

- [ ] **Step 3: Commit**

```powershell
git -C C:\redbearpad\gamepad-pcb add -A
git -C C:\redbearpad\gamepad-pcb commit -m "Netlist exportado y verificado contra el spec"
```

---

### Task 5: Generador de PCB — placement, contorno y nets

**Files:**
- Create: `scripts/gen_pcb.py`
- Create (generado): `redbearpad.kicad_pcb`

- [ ] **Step 1: Escribir `scripts/gen_pcb.py` (parte placement)**

Código completo (las TRACKS y zonas se añaden en la Task 6; este paso ya las deja
definidas pero la lista TRACKS puede ajustarse después):

```python
"""Genera redbearpad.kicad_pcb desde el netlist + tabla de placement del spec.
Ejecutar con el python de KiCad (tiene el modulo pcbnew).
"""
import os, re, sys
import pcbnew

HERE = os.path.dirname(os.path.abspath(__file__))
ROOT = os.path.normpath(os.path.join(HERE, ".."))
PCB = os.path.join(ROOT, "redbearpad.kicad_pcb")
NETFILE = os.path.join(ROOT, "redbearpad.net")
LOCAL_LIB = os.path.join(ROOT, "libs", "redbearpad.pretty")
KICAD_FP = r"C:\Program Files\KiCad\9.0\share\kicad\footprints"

def MM(x, y):
    return pcbnew.VECTOR2I(int(round(x * 1e6)), int(round(y * 1e6)))

def FMM(v):
    return int(round(v * 1e6))

# ---------- parsear netlist ----------
def balanced(text, start):
    depth = 0
    j = start
    while True:
        if text[j] == "(":
            depth += 1
        elif text[j] == ")":
            depth -= 1
            if depth == 0:
                return text[start:j + 1]
        j += 1

text = open(NETFILE, encoding="utf-8").read()
NETS = {}          # nombre -> [(ref, pin)]
idx = 0
while True:
    m = re.search(r"\(net\s+\(code", text[idx:])
    if not m:
        break
    blk = balanced(text, idx + m.start())
    name = re.search(r'\(name\s+"([^"]+)"\)', blk).group(1)
    nodes = [(n.group(1), n.group(2)) for n in
             re.finditer(r'\(node\s+\(ref\s+"([^"]+)"\)\s+\(pin\s+"([^"]+)"\)', blk)]
    if len(nodes) > 1:
        NETS[name] = nodes
    idx = idx + m.start() + len(blk)

# ---------- placement ----------
SW_FP = (LOCAL_LIB, "SW_Redragon_LowProfile_PCB_1.00u")
S14 = (os.path.join(KICAD_FP, "Connector_PinSocket_2.54mm.pretty"),
       "PinSocket_1x14_P2.54mm_Vertical")
S04 = (os.path.join(KICAD_FP, "Connector_PinSocket_2.54mm.pretty"),
       "PinSocket_1x04_P2.54mm_Vertical")
HOLE = (LOCAL_LIB, "MountingHole_3.1mm")

PLACE = {
    "SW1": (SW_FP, 16, 16, False), "SW2": (SW_FP, 32, 32, False),
    "SW3": (SW_FP, 16, 48, False), "SW4": (SW_FP, 32, 48, False),
    "SW5": (SW_FP, 48, 48, False), "SW6": (SW_FP, 64, 32, False),
    "SW7": (SW_FP, 80, 32, False), "SW8": (SW_FP, 80, 48, False),
    "J1": (S14, 40.38, 1.667, True),
    "J2": (S14, 55.62, 1.667, True),
    "J3": (S04, 30.0, 9.7, False),
    "H1": (HOLE, 4, 4, False), "H2": (HOLE, 92, 4, False),
    "H3": (HOLE, 4, 60, False), "H4": (HOLE, 92, 60, False),
}

board = pcbnew.NewBoard(PCB)

net_objs = {}
for name in NETS:
    n = pcbnew.NETINFO_ITEM(board, name)
    board.Add(n)
    net_objs[name] = n

fps = {}
for ref, ((lib, fpname), x, y, flip) in PLACE.items():
    fp = pcbnew.FootprintLoad(lib, fpname)
    assert fp is not None, (lib, fpname)
    fp.SetReference(ref)
    board.Add(fp)
    if flip:
        fp.Flip(MM(x, y), True)
    fp.SetPosition(MM(x, y))
    fp.SetOrientationDegrees(0)
    fps[ref] = fp

for name, nodes in NETS.items():
    for ref, pin in nodes:
        pad = fps[ref].FindPadByNumber(pin)
        assert pad is not None, (ref, pin)
        pad.SetNet(net_objs[name])

# ---------- asserts de posiciones de pads (el "test" de placement) ----------
def pad_at(ref, pin):
    p = fps[ref].FindPadByNumber(pin).GetPosition()
    return (p.x / 1e6, p.y / 1e6)

def close(a, b, tol=0.01):
    return abs(a[0] - b[0]) < tol and abs(a[1] - b[1]) < tol

assert close(pad_at("SW1", "1"), (19.8, 19.8))
assert close(pad_at("SW1", "2"), (16.0, 22.5))
assert close(pad_at("SW8", "1"), (83.8, 51.8))
assert close(pad_at("J1", "1"), (40.38, 1.667))
assert close(pad_at("J1", "14"), (40.38, 34.687))
assert close(pad_at("J2", "2"), (55.62, 4.207))
assert close(pad_at("J2", "8"), (55.62, 19.447))
assert close(pad_at("J3", "1"), (30.0, 9.7))
assert close(pad_at("J3", "4"), (30.0, 17.32))
assert fps["J1"].GetLayer() == pcbnew.B_Cu, "J1 debe estar en la cara inferior"
assert fps["J2"].GetLayer() == pcbnew.B_Cu, "J2 debe estar en la cara inferior"

# ---------- contorno: rect 96x64, esquinas r=1 ----------
def edge_seg(x1, y1, x2, y2):
    s = pcbnew.PCB_SHAPE(board)
    s.SetShape(pcbnew.SHAPE_T_SEGMENT)
    s.SetStart(MM(x1, y1)); s.SetEnd(MM(x2, y2))
    s.SetLayer(pcbnew.Edge_Cuts); s.SetWidth(FMM(0.1))
    board.Add(s)

def edge_arc(sx, sy, mx, my, ex, ey):
    a = pcbnew.PCB_SHAPE(board)
    a.SetShape(pcbnew.SHAPE_T_ARC)
    a.SetArcGeometry(MM(sx, sy), MM(mx, my), MM(ex, ey))
    a.SetLayer(pcbnew.Edge_Cuts); a.SetWidth(FMM(0.1))
    board.Add(a)

R = 1.0
K = R * (1 - 0.70710678)   # sagita para el punto medio del arco de 90 grados
edge_seg(R, 0, 96 - R, 0)
edge_seg(96, R, 96, 64 - R)
edge_seg(96 - R, 64, R, 64)
edge_seg(0, 64 - R, 0, R)
edge_arc(96 - R, 0, 96 - K, K, 96, R)        # esquina sup. der.
edge_arc(96, 64 - R, 96 - K, 64 - K, 96 - R, 64)  # inf. der.
edge_arc(R, 64, K, 64 - K, 0, 64 - R)        # inf. izq.
edge_arc(0, R, K, K, R, 0)                   # sup. izq.

# ---------- zonas GND ----------
for layer in (pcbnew.F_Cu, pcbnew.B_Cu):
    z = pcbnew.ZONE(board)
    z.SetLayer(layer)
    z.SetNet(net_objs["GND"])
    z.SetLocalClearance(FMM(0.3))
    z.SetMinThickness(FMM(0.25))
    outline = z.Outline()
    outline.NewOutline()
    for px, py in ((0, 0), (96, 0), (96, 64), (0, 64)):
        outline.Append(FMM(px), FMM(py))
    z.SetPadConnection(pcbnew.ZONE_CONNECTION_THERMAL)
    board.Add(z)

# ---------- pistas (TRACKS se completa/ajusta en Task 6) ----------
TRACKS = [
    # (net, capa, ancho_mm, [(x, y), ...])
    ("SW1", pcbnew.F_Cu, 0.25, [(19.8, 19.8), (30, 30), (38.5, 32.15), (40.38, 32.147)]),
    ("SW2", pcbnew.F_Cu, 0.25, [(35.8, 35.8), (39.2, 34.69), (40.38, 34.687)]),
    ("SW3", pcbnew.F_Cu, 0.25, [(19.8, 51.8), (19.8, 58), (57.5, 58), (57.5, 36.6), (55.62, 34.687)]),
    ("SW4", pcbnew.F_Cu, 0.25, [(35.8, 51.8), (43, 46), (43, 38), (53.5, 33.5), (55.62, 32.147)]),
    ("SW5", pcbnew.F_Cu, 0.25, [(51.8, 51.8), (58.5, 45), (58.5, 30.5), (55.62, 29.607)]),
    ("SW6", pcbnew.F_Cu, 0.25, [(67.8, 35.8), (62, 29), (57.5, 27.5), (55.62, 27.067)]),
    ("SW7", pcbnew.F_Cu, 0.25, [(83.8, 35.8), (70, 23), (57.5, 21.99), (55.62, 21.987)]),
    ("SW8", pcbnew.F_Cu, 0.25, [(83.8, 51.8), (75, 40), (62, 19.45), (55.62, 19.447)]),
    ("SDA", pcbnew.F_Cu, 0.25, [(30, 17.32), (36, 22), (38.5, 27.07), (40.38, 27.067)]),
    ("SCL", pcbnew.B_Cu, 0.25, [(30, 14.78), (34, 20), (38, 29.61), (40.38, 29.607)]),
    ("+3V3", pcbnew.F_Cu, 0.5, [(30, 12.24), (27.5, 14), (27.5, 36.5), (58.5, 36.5), (58.5, 4.21), (55.62, 4.207)]),
]
for net, layer, width, pts in TRACKS:
    for a, b in zip(pts, pts[1:]):
        t = pcbnew.PCB_TRACK(board)
        t.SetStart(MM(*a)); t.SetEnd(MM(*b))
        t.SetWidth(FMM(width)); t.SetLayer(layer)
        t.SetNet(net_objs[net])
        board.Add(t)

# ---------- serigrafia ----------
def silk(textstr, x, y, layer=pcbnew.F_SilkS, size=1.2, mirror=False):
    t = pcbnew.PCB_TEXT(board)
    t.SetText(textstr)
    t.SetPosition(MM(x, y))
    t.SetLayer(layer)
    t.SetTextSize(pcbnew.VECTOR2I(FMM(size), FMM(size)))
    t.SetTextThickness(FMM(0.2))
    t.SetMirrored(mirror)
    board.Add(t)

silk("REDBEARPAD", 75, 8, size=2.0)
for ref, (_, x, y, _) in PLACE.items():
    if ref.startswith("SW"):
        silk(ref, x - 6.5, y - 6.5, size=1.0)
for lbl, py in (("GND", 9.7), ("VCC", 12.24), ("SCL", 14.78), ("SDA", 17.32)):
    silk(lbl, 26.0, py, size=0.9)
# marco y orientacion del Blend Micro en la cara inferior
def silk_line(x1, y1, x2, y2, layer):
    s = pcbnew.PCB_SHAPE(board)
    s.SetShape(pcbnew.SHAPE_T_SEGMENT)
    s.SetStart(MM(x1, y1)); s.SetEnd(MM(x2, y2))
    s.SetLayer(layer); s.SetWidth(FMM(0.15))
    board.Add(s)
for (x1, y1, x2, y2) in ((38.8, 0.2, 38.8, 42.1), (57.2, 0.2, 57.2, 42.1),
                          (38.8, 42.1, 57.2, 42.1)):
    silk_line(x1, y1, x2, y2, pcbnew.B_SilkS)
silk("USB", 48, 3.0, layer=pcbnew.B_SilkS, mirror=True, size=1.2)
silk("BLEND MICRO", 48, 39.5, layer=pcbnew.B_SilkS, mirror=True, size=1.2)

# ---------- rellenar zonas y guardar ----------
filler = pcbnew.ZONE_FILLER(board)
filler.Fill(board.Zones())
board.Save(PCB)
print("PCB escrita:", PCB)
```

- [ ] **Step 2: Ejecutar y verificar asserts**

```powershell
& "C:\Program Files\KiCad\9.0\bin\python.exe" C:\redbearpad\gamepad-pcb\scripts\gen_pcb.py
```
Expected: `PCB escrita: ...` sin AssertionError. Si un assert de posición falla,
revisar el flip de J1/J2 (el orden Flip→SetPosition importa: flip primero, luego
posición) o el origen del footprint PinSocket (pin 1 debe quedar en la posición dada).

- [ ] **Step 3: Commit**

```powershell
git -C C:\redbearpad\gamepad-pcb add -A
git -C C:\redbearpad\gamepad-pcb commit -m "PCB generada: placement verificado, contorno, zonas, rutas iniciales"
```

---

### Task 6: DRC limpio

**Files:**
- Modify: `scripts/gen_pcb.py` (solo la lista `TRACKS` y, si hace falta, vías de costura)
- Regenerate: `redbearpad.kicad_pcb`

- [ ] **Step 1: Ejecutar DRC**

```powershell
& "C:\Program Files\KiCad\9.0\bin\kicad-cli.exe" pcb drc --severity-error --exit-code-violations --format json --output C:\redbearpad\gamepad-pcb\drc.json C:\redbearpad\gamepad-pcb\redbearpad.kicad_pcb
Get-Content C:\redbearpad\gamepad-pcb\drc.json
```
Expected (criterio de éxito de la tarea): exit 0, `violations: []` y
`unconnected_items: []`.

- [ ] **Step 2: Iterar rutas hasta DRC limpio**

Si hay violaciones de clearance: mover waypoints en `TRACKS` (ver notas de ruteo en
los Datos maestros: entrar a los pads de columna lateralmente, no cruzar columnas).
Si hay `unconnected_items` de GND (islas de zona): añadir vías de costura cerca de
la isla con este helper (añadir a `gen_pcb.py` antes del fill):

```python
def via(x, y):
    v = pcbnew.PCB_VIA(board)
    v.SetPosition(MM(x, y))
    v.SetDrill(FMM(0.3))
    v.SetWidth(FMM(0.6))
    v.SetLayerPair(pcbnew.F_Cu, pcbnew.B_Cu)
    v.SetNet(net_objs["GND"])
    board.Add(v)
# ejemplo: via(10, 10)
```
Regenerar (`gen_pcb.py`) y repetir el Step 1 hasta exit 0. `drc.json` no se
commitea (añadirlo a `.gitignore` si molesta).

- [ ] **Step 3: Commit**

```powershell
git -C C:\redbearpad\gamepad-pcb add -A
git -C C:\redbearpad\gamepad-pcb commit -m "Ruteo final: DRC sin errores ni unconnected"
```

---

### Task 7: Renders para revisión visual

**Files:**
- Create (generados): `docs/render_top.png`, `docs/render_bottom.png`

- [ ] **Step 1: Generar renders**

```powershell
& "C:\Program Files\KiCad\9.0\bin\kicad-cli.exe" pcb render --side top --output C:\redbearpad\gamepad-pcb\docs\render_top.png C:\redbearpad\gamepad-pcb\redbearpad.kicad_pcb
& "C:\Program Files\KiCad\9.0\bin\kicad-cli.exe" pcb render --side bottom --output C:\redbearpad\gamepad-pcb\docs\render_bottom.png C:\redbearpad\gamepad-pcb\redbearpad.kicad_pcb
```
Expected: dos PNG. Revisarlos (con la herramienta Read) contra el spec:
8 switches en sus posiciones, OLED arriba-izquierda, columnas J1/J2 en cara
inferior con marco "BLEND MICRO"/"USB", serigrafía legible y no superpuesta a pads.
Corregir posiciones de texto en `gen_pcb.py` si algo se solapa, regenerar PCB
(repetir DRC de Task 6 Step 1 tras cualquier regeneración) y re-renderizar.

- [ ] **Step 2: CHECKPOINT — mostrar renders al usuario**

Presentar ambos renders al usuario y esperar su visto bueno antes de exportar
Gerbers. Recordarle el checkpoint físico pendiente: medir los 3 agujeros del
switch real (poste Ø4.4 central; pines en (3.8, 3.8) y (0, 6.5) desde el centro,
Ø1.2) antes de pagar la fabricación.

- [ ] **Step 3: Commit**

```powershell
git -C C:\redbearpad\gamepad-pcb add -A
git -C C:\redbearpad\gamepad-pcb commit -m "Renders top/bottom para revision"
```

---

### Task 8: Gerbers + README

**Files:**
- Create (generados): `fabrication/gerbers/*`, `fabrication/redbearpad_jlcpcb.zip`
- Create: `README.md`

- [ ] **Step 1: Exportar Gerbers y drill**

```powershell
New-Item -ItemType Directory -Force C:\redbearpad\gamepad-pcb\fabrication\gerbers | Out-Null
& "C:\Program Files\KiCad\9.0\bin\kicad-cli.exe" pcb export gerbers --output C:\redbearpad\gamepad-pcb\fabrication\gerbers\ --layers "F.Cu,B.Cu,F.Mask,B.Mask,F.Silkscreen,B.Silkscreen,Edge.Cuts" --subtract-soldermask C:\redbearpad\gamepad-pcb\redbearpad.kicad_pcb
& "C:\Program Files\KiCad\9.0\bin\kicad-cli.exe" pcb export drill --output C:\redbearpad\gamepad-pcb\fabrication\gerbers\ --format excellon --excellon-units mm --drill-origin absolute C:\redbearpad\gamepad-pcb\redbearpad.kicad_pcb
```
Expected: archivos `.gbr` (7 capas) + `.drl` (PTH y NPTH) en `fabrication/gerbers/`.

- [ ] **Step 2: Empaquetar ZIP**

```powershell
Compress-Archive -Force -Path C:\redbearpad\gamepad-pcb\fabrication\gerbers\* -DestinationPath C:\redbearpad\gamepad-pcb\fabrication\redbearpad_jlcpcb.zip
```

- [ ] **Step 3: Escribir `README.md`**

Contenido completo:
```markdown
# RedBearPad — Gamepad de 8 botones con OLED para RedBearLab Blend Micro

PCB de 96 × 64 mm. Gamepad USB HID: 8 switches Redragon SMD RGB MX Low Profile
cableados directo a GPIO (pull-up interno), pantalla OLED 128×32 I2C, y la
Blend Micro V1.0 enchufada en la cara inferior (headers hembra 2×14, USB hacia
el borde superior).

## Archivos

- `redbearpad.kicad_pro/.kicad_sch/.kicad_pcb` — proyecto KiCad 9.
- `scripts/gen_sch.py`, `scripts/gen_pcb.py` — regeneran esquemático y PCB
  (ejecutar con el Python de KiCad: `C:\Program Files\KiCad\9.0\bin\python.exe`).
- `fabrication/redbearpad_jlcpcb.zip` — Gerbers + drill listos para JLCPCB.
- `docs/superpowers/specs/` — diseño aprobado; `docs/render_*.png` — vistas previas.

## Pedido en JLCPCB

1. jlcpcb.com → "Order now" → subir `fabrication/redbearpad_jlcpcb.zip`.
2. Opciones: 2 capas, 1.6 mm, HASL (todo por defecto sirve). Sin ensamblado.

## ⚠️ Antes de pagar

Medir con calibrador un switch real contra el footprint: poste central Ø4.4 mm
en el centro; pines a (3.8, 3.8) y (0, 6.5) mm del centro, Ø1.2 mm. Si no
coincide, ajustar `libs/redbearpad.pretty/SW_Redragon_LowProfile_PCB_1.00u.kicad_mod`
y regenerar.

## Conexiones (firmware)

| Función | Pin Arduino |
|---|---|
| SW1–SW6 | D5, D8, D9, D10, D11, D12 (`INPUT_PULLUP`, activo bajo) |
| SW7, SW8 | A0, A1 (`INPUT_PULLUP`, activo bajo) |
| OLED SDA/SCL | D2 / D3 (I2C, 3.3 V) |

Placa: usar el paquete `redbearlab:avr` (ver repo blend-micro-boards).

## Créditos

Footprint del switch: [rgoulter/keyboard-labs](https://github.com/rgoulter/keyboard-labs).
```

- [ ] **Step 4: Commit final**

```powershell
git -C C:\redbearpad\gamepad-pcb add -A
git -C C:\redbearpad\gamepad-pcb commit -m "Gerbers JLCPCB + README"
```

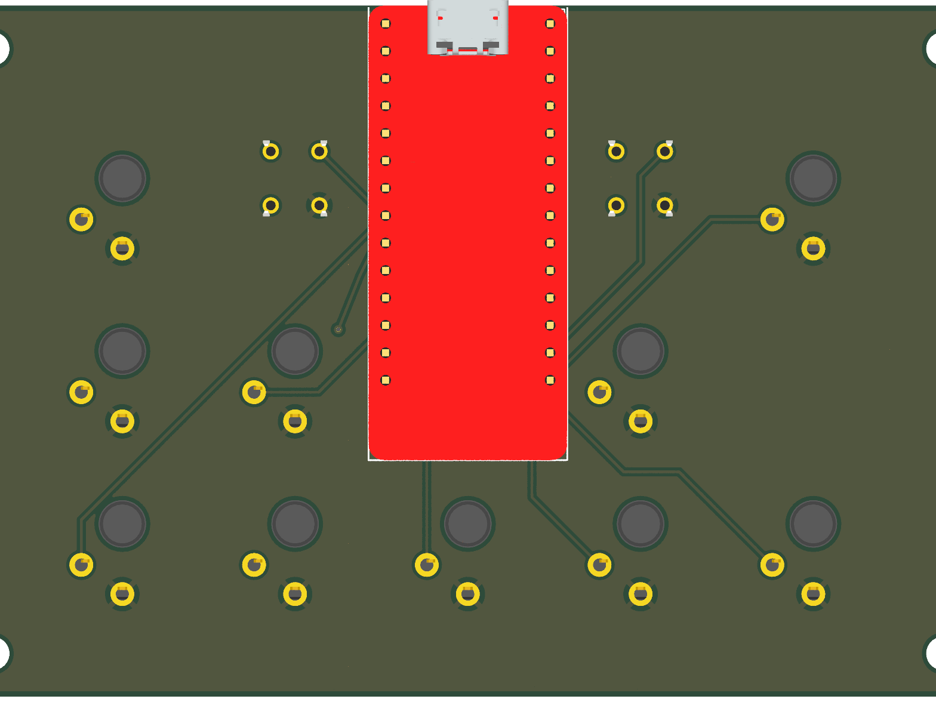
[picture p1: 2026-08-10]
docs/render_bottom.png

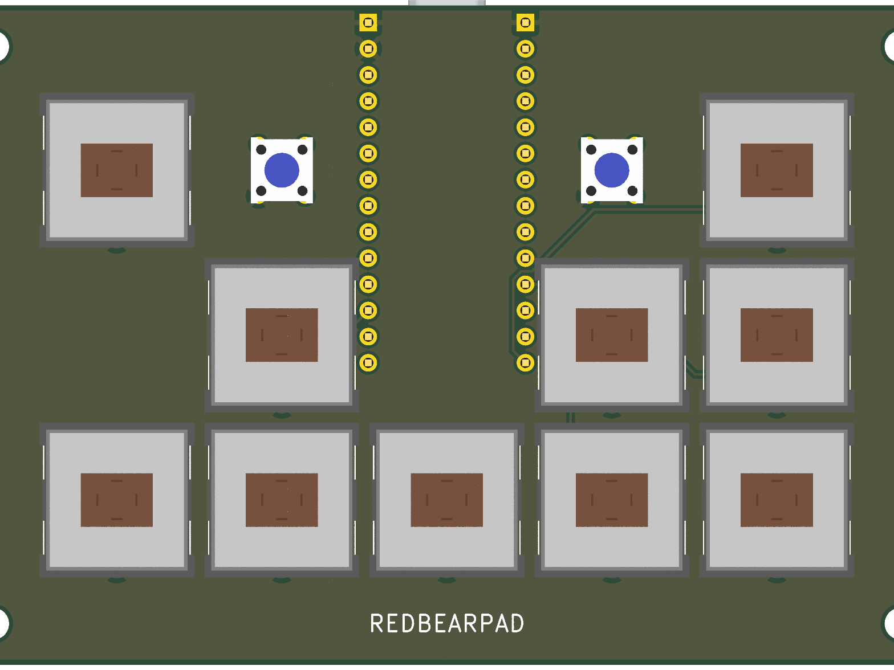
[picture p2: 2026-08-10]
docs/render_top.png

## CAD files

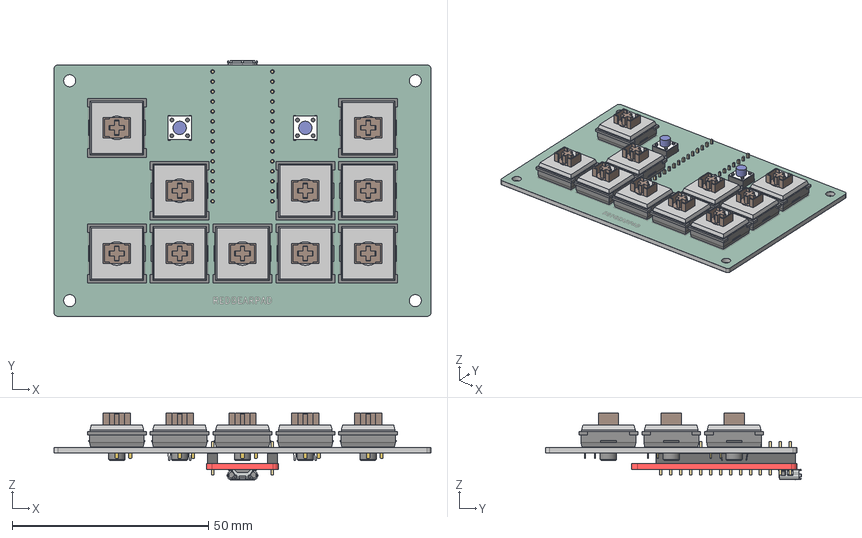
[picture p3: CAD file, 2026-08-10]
redbearpadv2.step
96.0 x 65.1 x 17.0 mm
Button x 10
Pins x 12
TactSwitch 6x6 x 2
shield
socket_housing
socket_plate
terminal
terminal001
terminal002
terminal003
terminal004
redbearpad_silkscreen
redbearpad_soldermask
redbearpad_PCB

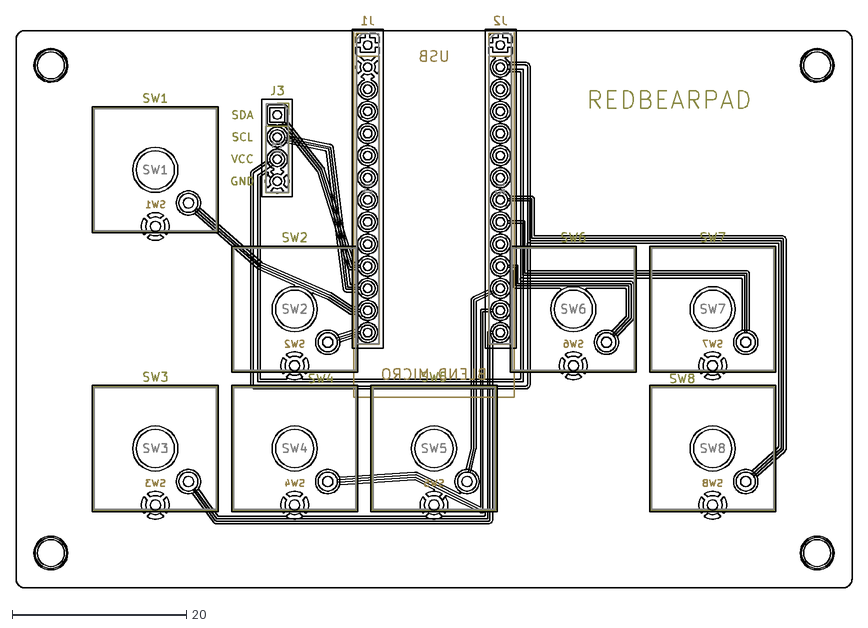
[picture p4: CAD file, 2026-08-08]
redbearpad_actual.dxf
96.0 x 65.6

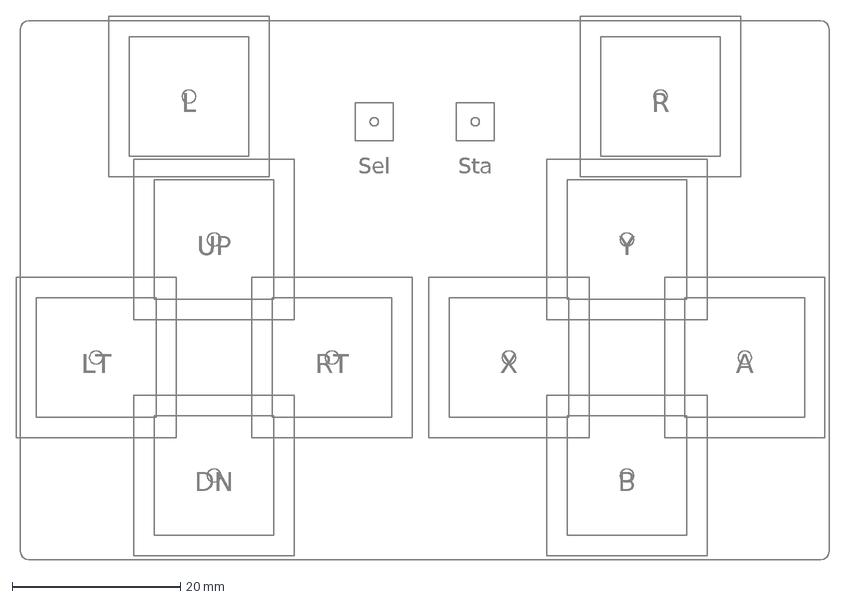
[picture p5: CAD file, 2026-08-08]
redbearpad_v2_layout.dxf
L
R
Sel
Sta
UP
Y
LT
RT
X
A
DN
B

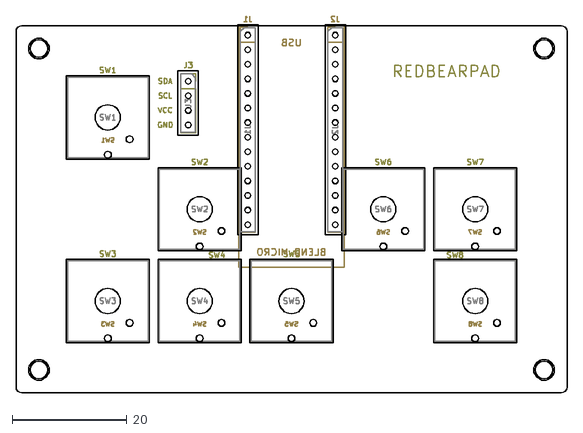
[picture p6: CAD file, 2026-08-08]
redbearpad_actual_mecanico.dxf
96.0 x 65.6

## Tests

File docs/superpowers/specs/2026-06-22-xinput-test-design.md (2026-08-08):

# Prueba XInput (mando Xbox) en la Blend Micro — Diseño

**Fecha:** 2026-06-22
**Estado:** Aprobado (experimento de viabilidad)

## Problema

El gamepad HID genérico funciona en Windows/joy.cpl pero los juegos vía Steam Input "no lo
ven" (problema DirectInput↔XInput). Se quiere que la placa **enumere como mando Xbox 360
(XInput)** para que cualquier juego lo reconozca. Antes de invertir en un board-variant a
medida, se **prueba el variant de fábrica** a ver si enumera en la Blend Micro.

## Solución (prueba)

Sketch mínimo de XInput con la librería `XInput` (dmadison) compilado para el variant
**`xinput:avr:micro`** ("Arduino Micro w/ XInput"). Se elige el de 16 MHz (no el Pro Micro
8 MHz) porque su PLL USB está configurado para un cristal de **16 MHz** — el de la Blend
Micro — así que es el que tiene chance de **enumerar**. El precio: corre a 16 MHz @ 3.3 V
(overclock), que puede glitchear; si enumera pero es inestable, el siguiente paso es un
variant a medida de 8 MHz.

## Alcance

- **Incluye:** sketch XInput mínimo (8 switches → stick + dpad + A/B/X/Y), debounce por
  integrador reutilizado, LED de heartbeat, compilación para `xinput:avr:micro`.
- **No incluye:** OLED, serial (XInput no tiene CDC), variant a medida, mapeos avanzados
  (gatillos, segundo stick). Es una prueba de enumeración.

## Estructura de archivos

```
firmware/redbearpad_xinput/redbearpad_xinput.ino   (NUEVO; sketch independiente)
```

No se tocan los sketches keypad ni gamepad.

## Componentes

### Sketch `redbearpad_xinput.ino`

- `#include <XInput.h>`; `XInput.begin()` en `setup()`, `XInput.setAutoSend(false)` (un
  reporte por ciclo con `XInput.send()`).
- Lectura de los 8 switches con el **debounce por integrador + muestreo fijo 1 ms** (igual
  que el gamepad).
- Mapeo Xbox (al cambiar algún estado):
  - Direcciones SW2/3/4/5 → **stick izquierdo** con `setJoystick(JOY_LEFT, up,down,left,
    right)` (deflexión completa, diagonales por SOCD) **y** `setDpad(up,down,left,right)`.
  - SW1/SW6/SW7/SW8 → `setButton(BUTTON_A/B/X/Y, ...)`.
- **LED 13 parpadea** (~1 Hz) como señal de "firmware vivo", ya que no hay serial.

## Restricciones operativas (importantes)

- **Sin Serial Monitor:** XInput no expone CDC; no hay diagnóstico por serie.
- **Re-flasheo manual:** tras correr XInput, la placa ya no entra sola al bootloader; hay que
  **doble-reset manual** (ventana ~8 s del Caterina) para volver a subir firmware.
- **Subida de ESTA prueba:** se hace sobre el firmware actual (que es CDC), así que el toque
  1200 bps aún funciona para este primer flasheo.

## Verificación

1. Compila para `xinput:avr:micro` sin errores (lo hace el agente).
2. En hardware (usuario): subir, y comprobar en Windows que aparece un **mando Xbox 360**
   (en `joy.cpl`, hardwaretester.com/gamepad o Steam → Controlador). Pulsar botones y
   direcciones para ver A/B/X/Y, dpad y stick.

## Resultado esperado y bifurcación

- **Enumera y responde estable** → ¡listo! Se documenta y se puede pulir (mapeo, etc.).
- **Enumera pero glitchea** (overclock 16 MHz @ 3.3 V) → siguiente: variant XInput a medida
  a 8 MHz con la corrección de PLL de la Blend Micro.
- **No enumera** → el variant de fábrica no sirve; ir directo al variant a medida.

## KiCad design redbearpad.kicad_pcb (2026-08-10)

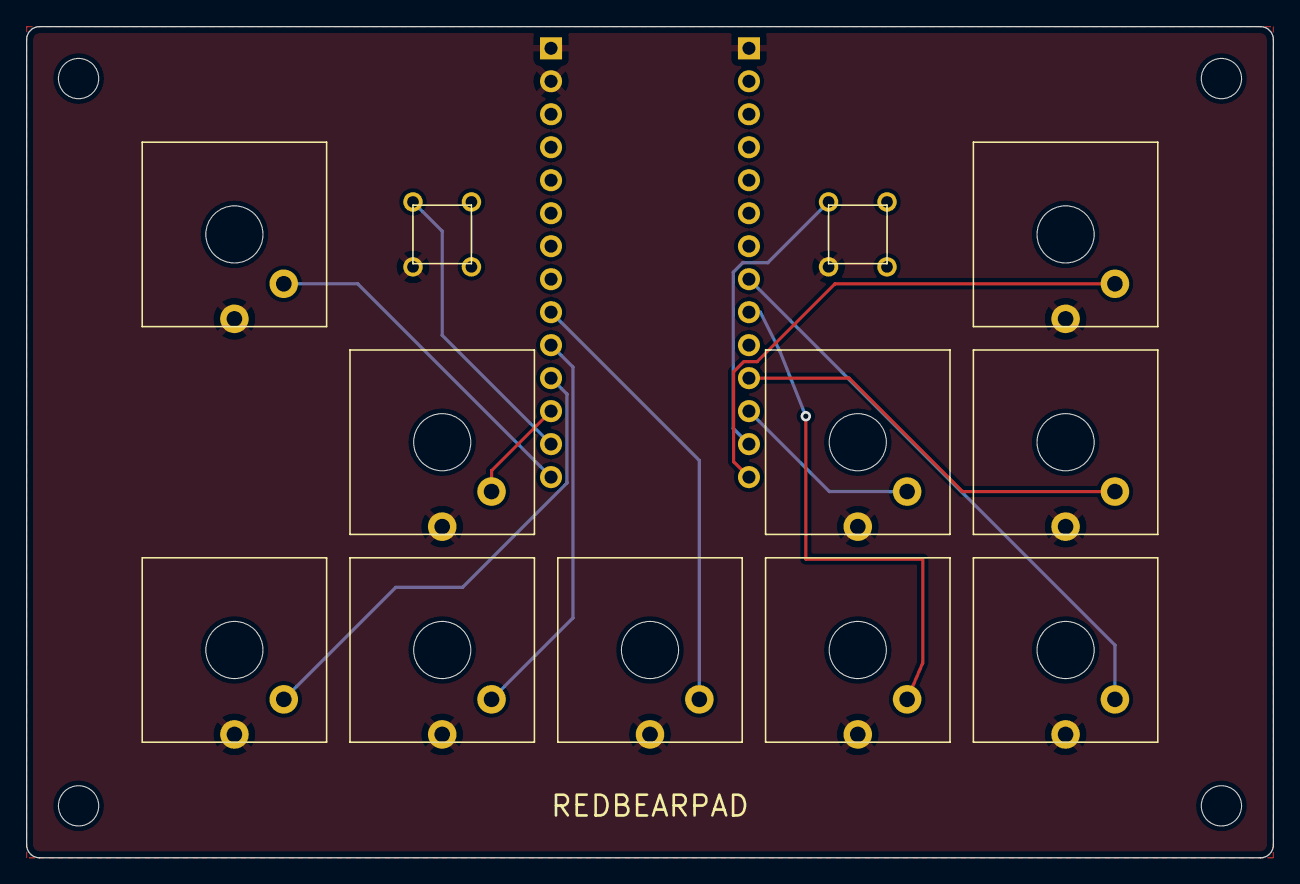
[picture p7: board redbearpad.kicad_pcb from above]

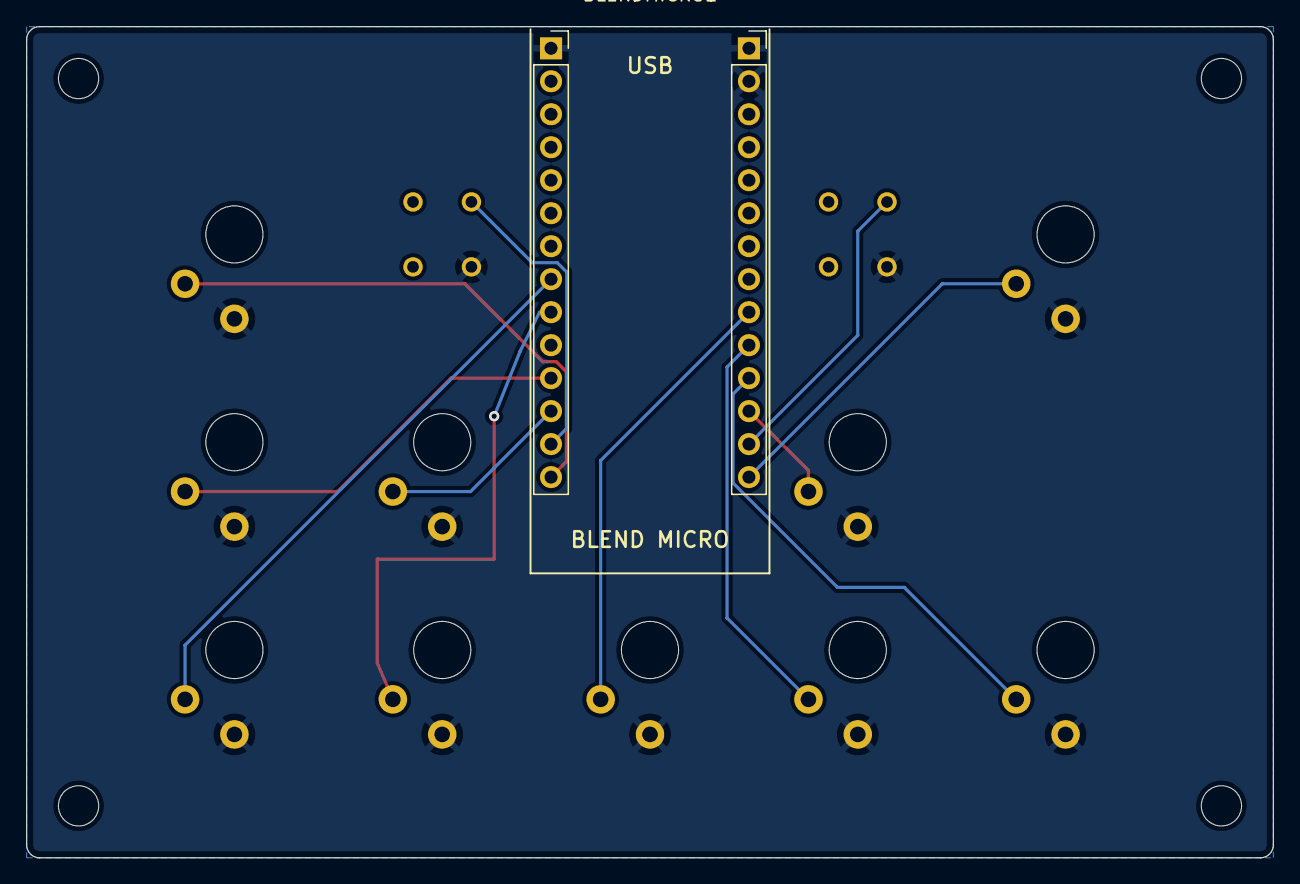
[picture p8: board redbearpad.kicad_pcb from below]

Board: 2 copper layers, 96.0 x 64.0 mm, 19 parts (3 on the bottom side), 13 nets.

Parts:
BLENDMICRO1: BlendMicro_Module
H1, H2, H3, H4: MountingHole_3.1mm
J1, J2: PinSocket_1x14_P2.54mm_Vertical
SW1, SW2, SW3, SW4, SW5, SW6, SW7, SW8, SW9, SW10: SW_Redragon_LowProfile_PCB_1.00u
SW11, SW12: SW_Tact_CAX; SW_Tact_CAX_4.5x4.5

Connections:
GND: J1.1, J1.2, J2.1, SW1.2, SW2.2, SW3.2, SW4.2, SW5.2, SW6.2, SW7.2, SW8.2, SW9.2, SW10.2, SW11.2, SW12.2
SW1: J1.12, SW1.1
SW2: J1.10, SW2.1
SW3: J1.11, SW3.1
SW4: J1.9, SW4.1
SW5: J2.12, SW5.1
SW6: J2.11, SW6.1
SW7: J2.9, SW7.1
SW8: J2.8, SW8.1
SW9: J1.14, SW9.1
SW10: J2.14, SW10.1
SW11: J1.13, SW11.1
SW12: J2.13, SW12.1

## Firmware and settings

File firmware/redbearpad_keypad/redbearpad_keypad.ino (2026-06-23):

/*
 * RedBearPad - Keypad USB HID de 8 teclas con OLED 128x32
 * Placa: RedBearLab Blend Micro V1.0 (ATmega32U4, core redbearlab:avr)
 *
 * El PC lo ve como un teclado: cada switch envia una tecla mientras se mantiene
 * pulsado. La OLED muestra en vivo que tecla esta activa.
 *
 * Mapeo de teclas:
 *   B1->Esc  B2->W  B3->A  B4->S  B5->D  B6->Espacio  B7->Enter  B8->Shift
 *
 * Librerias necesarias (todas desde el Gestor de librerias de Arduino):
 *   - HID-Project      (NicoHood) -> provee el Keyboard USB HID
 *   - Adafruit SSD1306
 *   - Adafruit GFX Library
 *
 * Mapeo de pines (fijado por la PCB redbearpad):
 *   SW1->D5  SW2->D8  SW3->D9  SW4->D10  SW5->D11  SW6->D12  SW7->A0  SW8->A1
 *   OLED I2C: SDA->D2  SCL->D3   (3.3 V)
 */

#include <HID-Project.h>
#include <Wire.h>
#include <Adafruit_GFX.h>
#include <Adafruit_SSD1306.h>

// ----- Switches: un pin por boton, a GND, con pull-up interno (activo en LOW) -----
const uint8_t NUM_BOTONES = 8;
const uint8_t PIN_BOTON[NUM_BOTONES] = { 5, 8, 9, 10, 11, 12, A0, A1 };

// ----- Tecla HID que envia cada boton (HID-Project KeyboardKeycode) -----
const KeyboardKeycode TECLA[NUM_BOTONES] = {
  KEY_ESC,        // B1
  KEY_W,          // B2
  KEY_A,          // B3
  KEY_S,          // B4
  KEY_D,          // B5
  KEY_SPACE,      // B6
  KEY_ENTER,      // B7
  KEY_LEFT_SHIFT  // B8
};
// Etiqueta corta para la OLED / monitor serie de cada tecla.
const char* const ETIQUETA[NUM_BOTONES] = {
  "Esc", "W", "A", "S", "D", "Spc", "Ent", "Sft"
};

// ----- OLED 128x32 por I2C -----
#define OLED_ANCHO   128
#define OLED_ALTO    32
#define OLED_RESET   -1      // comparte el reset de la placa
#define OLED_ADDR    0x3C    // direccion tipica de los modulos 128x32
Adafruit_SSD1306 oled(OLED_ANCHO, OLED_ALTO, &Wire, OLED_RESET);

// El teclado HID lo provee HID-Project mediante el objeto global `Keyboard`.

// Debounce por INTEGRADOR con histeresis, muestreado a intervalo FIJO.
// Por que: con pull-up interno (alta impedancia) la linea sube "sucia" al soltar.
// El debounce anterior ("estable N ms, se reinicia con CADA glitch") se atascaba:
// con el loop a ~16 kHz (Serial cerrado) cazaba cada glitch, reiniciaba el conteo
// y el release NUNCA se aceptaba -> la tecla quedaba pegada -> autorepeat del SO.
// El integrador sube con LOW y baja con HIGH; un glitch disperso solo mueve el
// contador 1 y no alcanza a voltear el estado. Muestrear a SAMPLE_MS fijo hace
// que el filtro NO dependa de la velocidad del loop (ni del Serial).
bool estadoPrev[NUM_BOTONES];        // estado aceptado (filtrado): true = pulsado
uint8_t integrador[NUM_BOTONES];     // 0..INTEGRADOR_MAX por tecla
uint32_t tUltimoSample = 0;          // ultimo instante de muestreo
const uint8_t SAMPLE_MS = 1;         // periodo de muestreo fijo (ms)
const uint8_t INTEGRADOR_MAX = 12;   // ~12 ms de senal predominante para cambiar

bool oledOk = false;

void dibujarPantalla(const bool pulsado[]) {
  if (!oledOk) return;
  oled.clearDisplay();
  oled.setTextSize(1);
  oled.setTextColor(SSD1306_WHITE);
  oled.setCursor(0, 0);
  oled.println(F("RedBearPad  keypad"));
  // Dos filas de 4: etiqueta de la tecla, en video inverso si esta pulsada.
  for (uint8_t i = 0; i < NUM_BOTONES; i++) {
    uint8_t col = i % 4;
    uint8_t fila = i / 4;
    int16_t x = col * 32;
    int16_t y = 14 + fila * 10;
    if (pulsado[i]) {
      oled.fillRect(x, y - 1, 30, 10, SSD1306_WHITE);
      oled.setTextColor(SSD1306_BLACK);
    } else {
      oled.setTextColor(SSD1306_WHITE);
    }
    oled.setCursor(x + 2, y);
    oled.print(ETIQUETA[i]);
  }
  oled.display();
}

// true si un dispositivo I2C ACKea en esa direccion. Usa el timeout de Wire, asi que
// no se cuelga si el bus esta trabado.
bool i2cResponde(uint8_t addr) {
  Wire.beginTransmission(addr);
  return (Wire.endTransmission() == 0);
}

// Escaneo del bus I2C: lista las direcciones que responden. Sirve para diagnosticar
// la OLED (suele estar en 0x3C o 0x3D). Si no responde nada, el problema esta en el
// cableado (SDA/SCL/VCC/GND) o el modulo, no en el sketch.
void escanearI2C() {
  Serial.println(F("=== Escaneo I2C ==="));
  uint8_t encontrados = 0;
  for (uint8_t addr = 1; addr < 127; addr++) {
    if (i2cResponde(addr)) {
      Serial.print(F("  dispositivo en 0x"));
      if (addr < 16) Serial.print('0');
      Serial.println(addr, HEX);
      encontrados++;
    }
  }
  if (encontrados == 0)
    Serial.println(F("  nada respondio -> revisar SDA/SCL/VCC/GND o el modulo OLED"));
  else {
    Serial.print(F("  total dispositivos: "));
    Serial.println(encontrados);
  }
  Serial.println(F("  (la OLED 128x32 suele estar en 0x3C o 0x3D)"));
}

void setup() {
  Serial.begin(115200);             // monitor serie (CDC sobre USB); no bloquea si no hay PC
  for (uint8_t i = 0; i < NUM_BOTONES; i++) {
    pinMode(PIN_BOTON[i], INPUT_PULLUP);
    estadoPrev[i] = false;          // sin pulsar
    integrador[i] = 0;              // integrador en reposo (soltado)
  }

  // CLAVE: timeout del I2C antes de tocar el bus. En AVR, Wire se cuelga para
  // siempre si el bus se traba (SDA/SCL retenida, ruido, pull-ups debiles) y eso
  // congelaria TODO el loop, teclado incluido. Con timeout, una transaccion
  // trabada aborta a los 25 ms, se resetea el bus y el teclado sigue vivo.
  Wire.begin();
  Wire.setWireTimeout(25000 /*us*/, true /*resetea el bus al expirar*/);

  // La pantalla es opcional. PRIMERO se verifica por I2C si el chip realmente responde:
  // Adafruit_SSD1306::begin() devuelve true aunque NO haya pantalla (solo reserva el
  // buffer, no comprueba el ACK). Probando el ACK antes, oledOk refleja la presencia
  // real y se inicializa en la direccion que de verdad contesta (0x3C o 0x3D).
  uint8_t oledAddr = 0;
  if (i2cResponde(0x3C))      oledAddr = 0x3C;
  else if (i2cResponde(0x3D)) oledAddr = 0x3D;
  oledOk = (oledAddr != 0) && oled.begin(SSD1306_SWITCHCAPVCC, oledAddr);

  // DIAGNOSTICO: con nada pulsado todos los pines deben leer HIGH. Si alguno
  // arranca en LOW, ese pin esta clavado (mal cableado, puente, o uso on-board)
  // y generaria una tecla fantasma. Esperar a que el monitor serie se conecte.
  uint32_t t0 = millis();
  while (!Serial && millis() - t0 < 3000) { /* espera hasta 3 s al PC */ }
  Serial.println(F("=== RedBearPad keypad - autodiagnostico de pines ==="));
  bool algunoClavado = false;
  for (uint8_t i = 0; i < NUM_BOTONES; i++) {
    bool low = (digitalRead(PIN_BOTON[i]) == LOW);
    Serial.print(ETIQUETA[i]);
    Serial.print(F(" (pin "));
    Serial.print(PIN_BOTON[i]);
    Serial.print(F("): "));
    Serial.println(low ? F("LOW  <-- CLAVADO sin pulsar!") : F("HIGH ok"));
    if (low) algunoClavado = true;
  }
  Serial.println(algunoClavado
    ? F("AVISO: hay pines en LOW al arranque -> revisar cableado/HW")
    : F("Pines OK. Arrancando teclado HID."));

  // Diagnostico de pantalla: escaneo del bus y estado de la OLED.
  escanearI2C();
  Serial.print(F("OLED: "));
  Serial.println(oledOk ? F("detectada e inicializada")
                        : F("NO detectada (ver escaneo I2C de arriba)"));

  Keyboard.begin();                 // arranca el HID despues del diagnostico

  if (oledOk) dibujarPantalla(estadoPrev);   // rejilla inicial (todo sin pulsar)
}

void loop() {
  uint32_t ahora = millis();
  bool huboCambio = false;
  bool pulsadoAhora[NUM_BOTONES];
  for (uint8_t i = 0; i < NUM_BOTONES; i++) pulsadoAhora[i] = estadoPrev[i];

  // Muestreo a intervalo FIJO (SAMPLE_MS): el filtro no depende de cuan rapido
  // corra el loop, asi que se comporta igual con el Serial abierto o cerrado.
  if (ahora - tUltimoSample >= SAMPLE_MS) {
    tUltimoSample = ahora;

    for (uint8_t i = 0; i < NUM_BOTONES; i++) {
      // INPUT_PULLUP: pin en LOW = boton pulsado.
      bool leido = (digitalRead(PIN_BOTON[i]) == LOW);

      // Integrador: sube hacia INTEGRADOR_MAX con LOW, baja hacia 0 con HIGH.
      if (leido) { if (integrador[i] < INTEGRADOR_MAX) integrador[i]++; }
      else       { if (integrador[i] > 0)              integrador[i]--; }

      // Histeresis: solo se voltea en los extremos; el ruido disperso (que no
      // llega a un extremo) mantiene el estado anterior y no genera eventos.
      bool nuevo = estadoPrev[i];
      if (integrador[i] >= INTEGRADOR_MAX) nuevo = true;   // pulsado confirmado
      else if (integrador[i] == 0)         nuevo = false;  // soltado confirmado

      if (nuevo != estadoPrev[i]) {
        estadoPrev[i] = nuevo;
        pulsadoAhora[i] = nuevo;
        huboCambio = true;
        // press mantiene la tecla mientras este pulsado; release al soltar.
        if (nuevo) Keyboard.press(TECLA[i]);
        else       Keyboard.release(TECLA[i]);
        // Eco por el monitor serie.
        Serial.print(ETIQUETA[i]);
        Serial.println(nuevo ? F(" pulsado") : F(" soltado"));
      }
    }
  }

  // Refrescar la OLED al cambiar, y ademas un refresco lento de respaldo (~4 Hz)
  // por si la pantalla pierde el contenido. Volcar el framebuffer en CADA vuelta
  // saturaba el I2C y dejaba sin tiempo al USB (HID + Serial) -> el "colapso".
  static uint32_t ultimoRefresco = 0;
  if (oledOk && (huboCambio || ahora - ultimoRefresco > 250)) {
    dibujarPantalla(pulsadoAhora);
    ultimoRefresco = ahora;
  }
}

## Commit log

2026-06-13 Spec de diseno: gamepad PCB 8 botones + OLED para Blend Micro
2026-06-13 Spec: orden y posicion de pines OLED verificados con foto del modulo
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2026-06-13 Esquematico generado por script, ERC limpio
    [redbearpad.kicad_sch]
2026-06-13 gen_sch: UUIDs deterministas y gitignore de __pycache__
    [redbearpad.kicad_sch]
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2026-06-13 PCB generada: placement verificado, contorno, zonas, rutas iniciales
    [redbearpad.kicad_pcb]
2026-06-13 Ruteo final: DRC sin errores ni unconnected
    [redbearpad.kicad_pcb]
2026-06-13 gen_pcb: limpieza menor (quitar import sys, comentar path KiCad y parser netlist)
    [redbearpad.kicad_pcb]
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2026-06-13 Gerbers JLCPCB + README
    [redbearpad-B_Cu.gbl, redbearpad-B_Mask.gbs, redbearpad-B_Silkscreen.gbo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]
2026-06-18 Corregir orden de pines OLED a SDA/SCL/VCC/GND segun ajuste fisico del modulo
    - J3 reordenado en gen_sch.py y verify_netlist.py
    - Reruteo de SDA/SCL/+3V3 a las nuevas posiciones de pad; SCL despeja el pad +3V3
    - Serigrafia OLED invertida; renders y gerbers regenerados; spec actualizado
    - DRC 0 violaciones / 0 unconnected, ERC 0, netlist OK
    [redbearpad-B_Cu.gbl, redbearpad-B_Mask.gbs, redbearpad-B_Silkscreen.gbo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]
2026-06-18 Firmware de prueba: gamepad USB HID 8 botones + OLED (compila para Blend Micro)
    Sketch redbearpad_gamepad.ino con Joystick (Heironimus) + Adafruit SSD1306.
    Verificado: compila 20586 B / 71% flash en blendmicro16 y blendmicro8.
2026-06-18 Firmware: cambiar a HID-Project (Gamepad) para evitar colision de Joystick.h
    La libreria Joystick instalada es la de Giuseppe Martini (lee joysticks
    analogicos), que choca con la de Heironimus por compartir Joystick.h.
    HID-Project (NicoHood, indice oficial) usa Gamepad y no colisiona.
    Verificado: compila 18446 B / 64% en blendmicro16 y blendmicro8 con solo
    librerias del Gestor.
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2026-06-20 Firmware: debounce por integracion (rechaza crosstalk SW1->SW2)
    El debounce lockout dejaba pasar glitches breves; al pulsar SW1 (D5) se colaba
    una pulsacion fantasma en SW2 (D8), pines adyacentes en J1. Ahora se exige
    lectura estable 25 ms antes de aceptar un cambio.
    [redbearpad_keypad.ino]
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2026-06-20 Firmware: timeout de I2C para que un bus OLED trabado no congele el teclado
    Wire.setWireTimeout(25ms, reset): si el I2C se traba, aborta y sigue, en vez de colgar el loop. Cumple la promesa de pantalla opcional.
    [redbearpad_keypad.ino]
2026-06-23 fix(firmware): debounce por integrador con muestreo fijo (independiente del Serial)
    El debounce anterior (estable N ms, reinicia con cada glitch) se atascaba con el
    loop a maxima velocidad (Serial cerrado): cazaba el ruido al soltar y nunca aceptaba
    el release, dejando la tecla pegada + autorepeat del SO. Se reemplaza por un
    integrador con histeresis muestreado a 1 ms fijo, asi el filtro no depende de la
    velocidad del loop. Latencia ~12 ms.
    Nota: la causa raiz del sintoma era el overclock (compilar a 16 MHz a 3.3V); usar
    siempre blendmicro8. Este cambio es robustez complementaria.
    [redbearpad_keypad.ino]
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2026-06-23 fix(gamepad): mapear las direcciones tambien al stick izquierdo
    El hat (dPad1) lo lee joy.cpl (POV) pero el navegador y la mayoria de juegos no lo
    interpretan como direccion. Se anaden xAxis/yAxis (deflexion completa) para que el
    movimiento sea legible universalmente; el hat se mantiene para menus/joy.cpl.
    [redbearpad_gamepad.ino]
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2026-06-29 docs(xinput): README del build XInput (paquete, board Micro, doble-reset)
2026-06-29 feat(pcb-v2): DXF de layout 12 botones (10 MX + 2 tact CAX) sobre contorno 96x64
    [redbearpad_v2_layout.dxf]
2026-06-29 feat(pcb-v2): export DXF del PCB actual (completo + mecanico) como base para el rediseno
    [redbearpad_actual.dxf, redbearpad_actual_mecanico.dxf]
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2026-06-29 feat(pcb-v2): esquematico a 12 entradas (10 MX + 2 tact), OLED fuera
    [redbearpad.kicad_sch]
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2026-06-29 feat(pcb-v2): placement de 12 footprints, OLED fuera (sin pistas aun)
    [redbearpad.kicad_pcb]
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2026-06-29 feat(pcb-v2): ruteo completo de 12 nets (Freerouting 11 + SW7 con via a mano), DRC de cobre limpio
    [redbearpad.dsn, redbearpad.kicad_pcb]
2026-06-29 feat(pcb-v2): serigrafia limpia (refdes ocultos, etiquetas duplicadas fuera); quedan 8 silk-over-pad cosmeticas del tact
    [redbearpad.kicad_pcb]
2026-06-29 build(pcb-v2): gerbers + drill regenerados (board v2 ruteado)
    [redbearpad-B_Courtyard.gbr, redbearpad-B_Cu.gbl, redbearpad-B_Fab.gbr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]
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2026-06-30 fix(pcb-v2): drill incompleto en el ZIP (faltaban SW7/X, SW10/R, tacts y via)
    El export previo dejo archivos PTH/NPTH viejos (60 holes) que no incluian SW7,
    SW10, los tact ni la via, y un redbearpad.drl mezclado. Re-export limpio:
    NPTH 14 + PTH 57 = 71 holes correctos. ZIPs reconstruidos.
    [redbearpad-B_Courtyard.gbr, redbearpad-B_Cu.gbl, redbearpad-B_Fab.gbr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]
2026-07-02 fix(xinput): deshabilitar JTAG por software (JTD) - X/Y (PF7/PF6=TDI/TDO) fantasma
    X=A0=PF7=TDI y Y=A1=PF6=TDO son pines JTAG del 32U4. Con JTAG activo no son
    GPIO limpio -> lecturas fantasma solo en X/Y. Se escribe JTD dos veces en setup().
    [redbearpad_xinput.ino]
2026-07-02 revert(xinput): quitar disable de JTAG - el fantasma X/Y era soldadura, no JTAG
    Evidencia: con el keypad @ 8MHz (en spec), A0/A1 leian HIGH ok en reposo y el
    acople aparecia al pulsar (puente fisico D12/A0/A1). Ruleado JTAG y overclock.
    Corregida la soldadura -> firmware XInput vuelve a su version conocida-buena.
    [redbearpad_xinput.ino]
2026-07-31 Update measurement instructions in README
    Corrected terminology from 'calibrador' to 'pie de metro' for clarity.
2026-08-08 fix(xinput): salir del overclock (CPU 8 MHz) y ABXY segun convencion Xbox
    Dos correcciones validadas juntas en una sesion de 30 min en Steam, sin
    cuelgues ni botones fantasma.
    1. Prescaler CLKPR (division por dos) al inicio de setup(): el 32U4 a
    16 MHz @ 3.3V esta fuera de spec (curva freq-vs-Vcc: ~10.7 MHz maximo
    a 3.3V) y glitcheaba al calentar, acoplando botones vecinos tras ~5
    min. Se baja solo la CPU a 8 MHz; el PLL del USB no se toca (PINDIV se
    fija en compilacion segun F_CPU=16000000, correcto para el cristal de
    16 MHz de la Blend Micro), asi que sigue enumerando como mando Xbox
    360. Efecto temporal: millis() y el timing corren a la mitad, o sea
    heartbeat ~0.5 Hz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
    [redbearpad_xinput.ino]
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2026-08-09 feat(3d): modelo 3D del switch Redragon MX Low Profile
    Se adjunta el STEP "ReDragon_ZT04_MX-LP" (libreria "Switches/REDragon_MX_
    LowProfile_ZT04", autor "saper") a los 10 switches Redragon de la placa.
    El archivo se encontro en la raiz de C:\redbearpad y se copio a
    libs/redbearpad.3dshapes/ con el nombre del footprint. El tact CAX
    (Start/Select) y la Blend Micro quedan sin modelo por ahora, no hay
    STEP disponible para ninguno de los dos.
    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
    [redbearpad.kicad_pcb]
2026-08-09 fix(3d): rotar 180 grados el modelo del switch Redragon
    Ajuste solicitado por el usuario tras revisar el render anterior.
    - libs/redbearpad.pretty/SW_Redragon_LowProfile_PCB_1.00u.kicad_mod:
    rotate xyz de (0 0 0) a (0 0 180).
    - scripts/attach_3d_models.py: corregido un bug real al reaplicar la
    rotacion sobre el board ya ruteado. `fp.Models()` es un wrapper SWIG
    de std::vector; iterarlo con `for m in fp.Models()` entrega copias
    por valor, asi que mutar el objeto obtenido en el loop NO se
    propagaba al vector real (confirmado: el primer intento reporto
    "actualizado" pero al releer el .kicad_pcb la rotacion seguia en 0).
    El fix indexa con `models[i]` para escribir sobre el element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
    [redbearpad.kicad_pcb]
2026-08-09 feat(3d): placeholder dimensionalmente real de la Blend Micro
    Se descarta usar un modelo de Arduino Micro como sustituto: sus medidas
    oficiales (48x18mm) no calzan con la Blend Micro real (42.087x18.4mm,
    confirmado contra el DXF oficial del fabricante) -- 14% mas larga, y
    probablemente con headers en otro patron. Sustituirlo habria dado un
    render dimensionalmente falso.
    En su lugar se genera un placeholder propio a partir de datos reales:
    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
    [redbearpad.kicad_pcb]
2026-08-09 feat(3d): usar el modelo real de la Blend Micro (BlendMicro_Module_V1)
    El usuario modelo la Blend Micro completa (PCB + 2 headers de 14 pines +
    conector micro-USB) y la dejo en libs/redbearpad.3dshapes/
    BlendMicro_Module_V1.step. Reemplaza el placeholder plano generado en el
    commit anterior.
    - BlendMicro_Module.kicad_mod: (model ...) repuntado a
    BlendMicro_Module_V1.step. Offset/escala/rotacion en cero -- igual que
    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
    [redbearpad.kicad_pcb]
2026-08-09 fix(3d): espejar la Blend Micro y quitar el socket duplicado de J1/J2
    Dos correcciones pedidas por el usuario tras revisar el render anterior.
    1. Espejado izquierda/derecha de BlendMicro_Module_V1. Se probo primero
    el camino obvio -- scale (xyz -1 1 1) en el bloque (model ...) del
    footprint -- y fallo: negar una escala en un solido B-rep invierte la
    orientacion de las caras sin re-triangular, KiCad hace back-face
    culling y el cuerpo del PCB desaparecia casi entero (quedaba un borde
    degenerado, verificado con render). Fix real:
    scripts/mirror_blendmicro_step.py usa CadQuery/OCC para aplicar una
    reflexion geometrica de verdad (Shape.mirror sobre el plano YZ) a
    cada sub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
    [redbearpad.kicad_pcb]
2026-08-09 fix(3d): rotar 180 en Y la Blend Micro en vez de mirror en X
    El usuario reporto que tras el mirror los pines de los headers apuntaban
    para el lado equivocado (hacia afuera en vez de hacia J1/J2). Verificado
    numericamente (centroides + volumen + validez topologica de las 14
    sub-partes) que el mirror en X del commit anterior era geometricamente
    exacto y no toco Y/Z para nada -- asi que el problema de los pines ya
    estaba en el archivo original, solo que no se habia notado hasta mirar
    de cerca.
    La solucion es mas simple que el problema: el modulo necesitaba DOS
    correcciones (mirror en X para el header L/R + flip en Z para que los
    pines apunten hacia adentro), y espejar en dos ejes distintos equ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
2026-08-09 fix(3d): desplazar la Blend Micro -4.10mm en Z
    Ajuste de profundidad de montaje pedido por el usuario tras revisar el
    render con la orientacion ya corregida (rotate 0 180 0). Offset (xyz 0 0
    -4.10) en el bloque (model ...) del footprint BlendMicro_Module, mismo
    valor aplicado a la instancia BLENDMICRO1 ya colocada en el board
    (indexando el vector de modelos, no iterando).
    Verificado: netlist OK, DRC de cobre limpio (0 sin conectar, las 8 avisos
    cosmeticas de siempre). Render bottom confirma el modulo mas alejado de
    la placa -- las etiquetas de serigrafia B.SilkS "USB"/"BLEND MICRO", antes
    tapadas por el cuerpo del modulo, ahora quedan visibles.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
    [redbearpad.kicad_pcb]
2026-08-09 fix(3d): corregir el signo del offset Z de la Blend Micro (+4.10mm)
    El commit anterior aplico -4.10mm; el usuario confirmo que el signo
    correcto es +4.10mm. offset (xyz 0 0 4.10) en el bloque (model ...) del
    footprint BlendMicro_Module y en la instancia BLENDMICRO1 del board.
    cosmeticas de siempre). Render bottom/perspectiva: el modulo completo
    (PCB + headers + conector USB) vuelve a verse solido y sin recortes,
    correctamente apoyado.
    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
    [redbearpad.kicad_pcb]
2026-08-10 feat(3d): modelo 3D generico para los tact Start/Select
    Se busco un footprint generico compatible en la libreria estandar de
    KiCad (Button_Switch_THT/SMD) para el CAX C39832249 (4.5x4.5mm, pines
    diagonales a 2.25/2.5mm) y no hay ninguno que calce: los dos hits por
    patron de pines (SW_SPST_Omron_B3F-315x_Angled, SW_Tactile_SKHH_Angled)
    son switches acodados (right-angle), mecanicamente distintos al montaje
    vertical real.
    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
    [redbearpad.kicad_pcb]
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2026-08-10 chore: commitear redbearpadv2.step (export manual STEP consolidado)
    STEP de toda la placa exportado por el usuario desde KiCad
    (File > Export > STEP), referenciado ya en redbearpad.kicad_pro.
    [redbearpadv2.step]
